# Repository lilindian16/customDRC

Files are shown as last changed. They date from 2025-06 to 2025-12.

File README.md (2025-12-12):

# Custom DRC for the Bit10 DSP

## Reverse Engineering

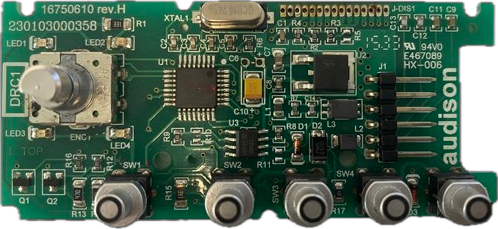
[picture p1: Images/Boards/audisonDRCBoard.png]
Bit10 DRC PCB with screen removed


### Bit10 DRC Schema

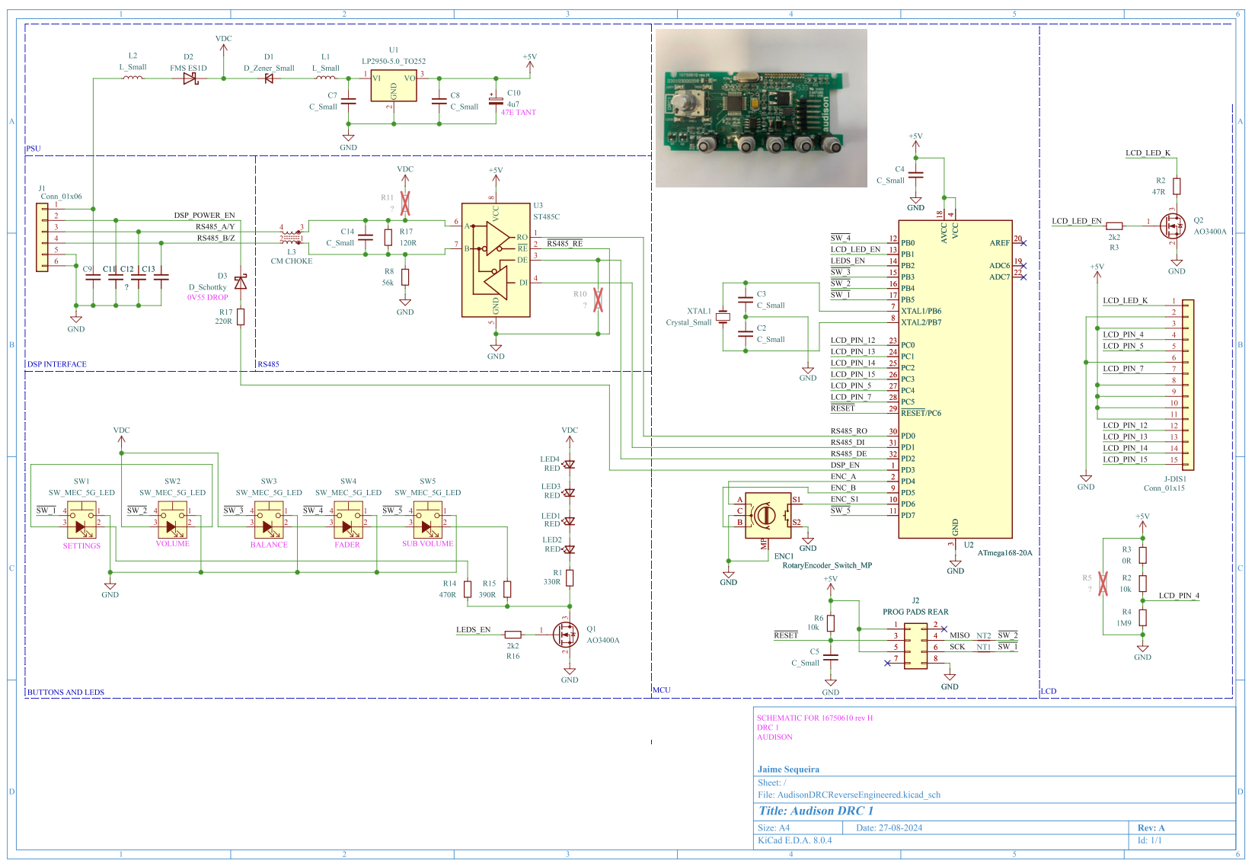
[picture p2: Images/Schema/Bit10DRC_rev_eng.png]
Bit10 DRC schema


## CustomDRC

### Bare PCB

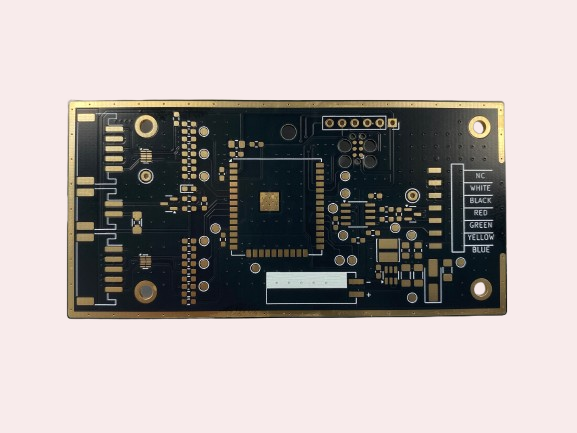
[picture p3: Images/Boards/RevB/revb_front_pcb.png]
Rev B PCB Front


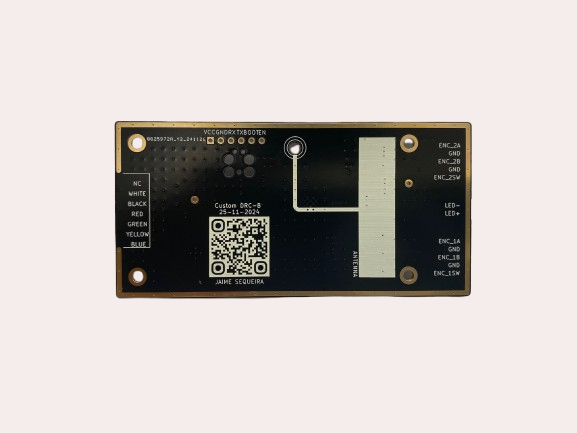
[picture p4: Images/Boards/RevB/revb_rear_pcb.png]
Rev B PCB Rear


### Assembled Board

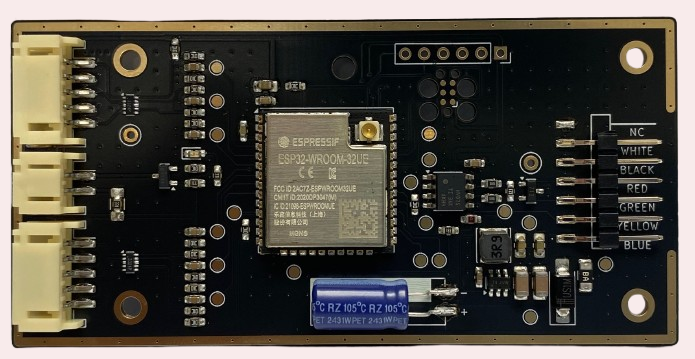
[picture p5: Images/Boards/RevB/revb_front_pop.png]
Reb B PCB Assembled


Boards can be programmed via TC2030 header or 2.54mm pin header (left unpopulated). Once programmed,
further updates can be handled via the OTA Update interface through the local webapp

### Board Bringup - Scope Captures

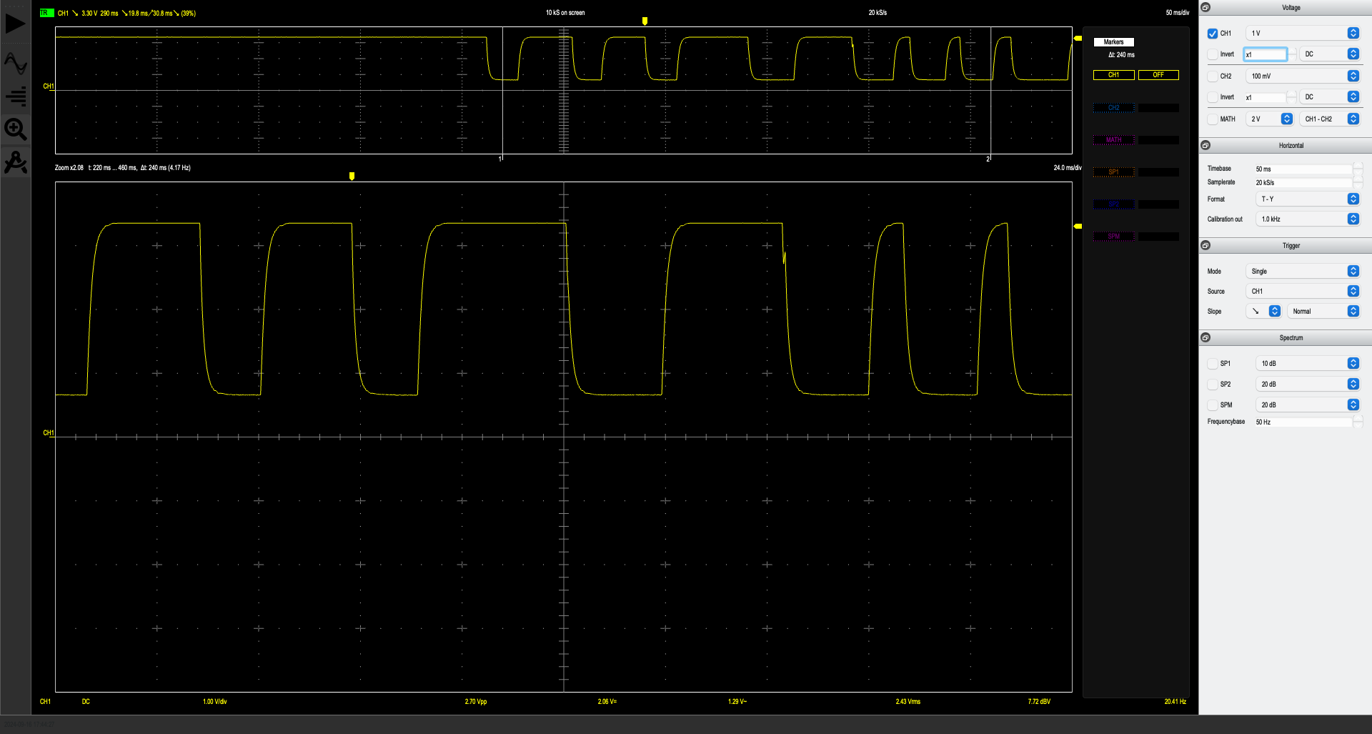
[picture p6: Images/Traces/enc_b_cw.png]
Encoder Pin B during rotation


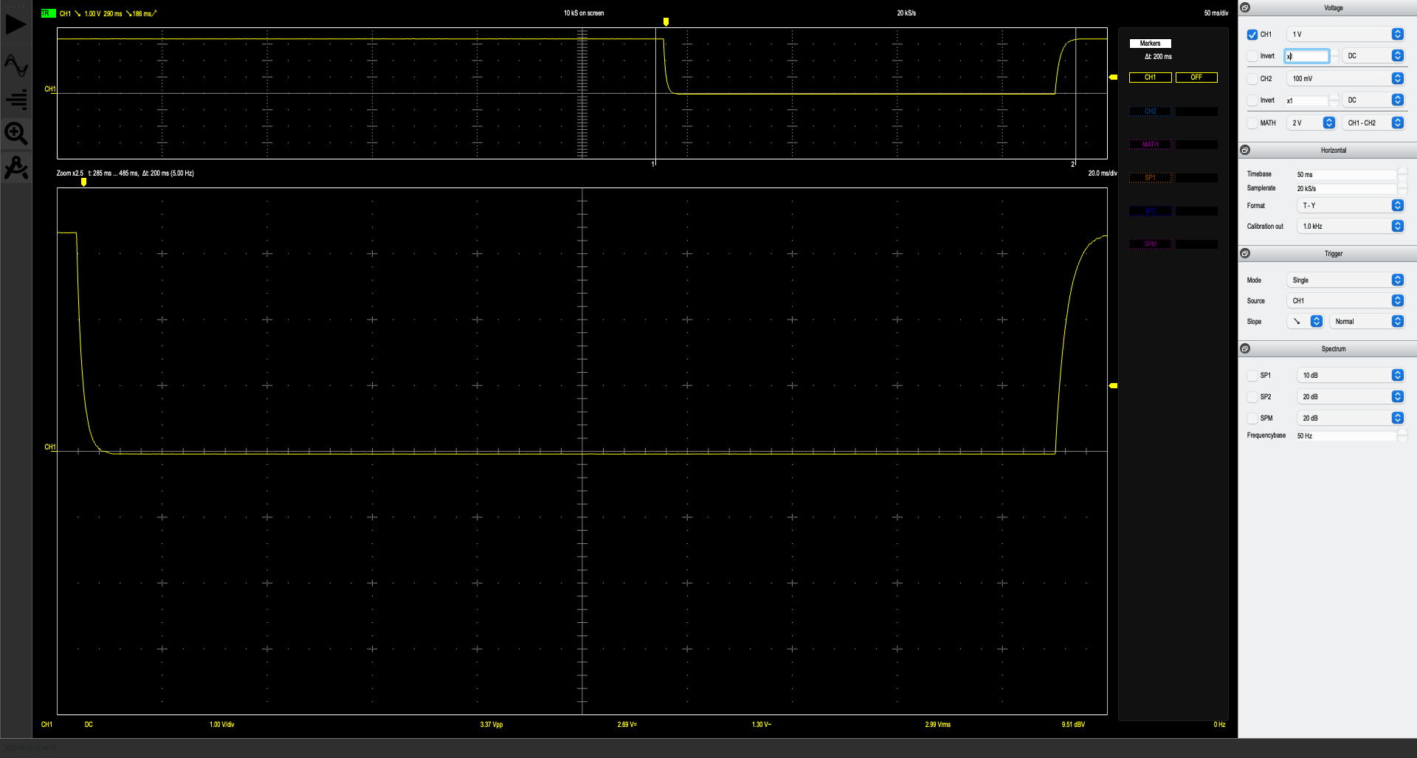
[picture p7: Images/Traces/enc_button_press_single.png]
Capture of button signal on single press


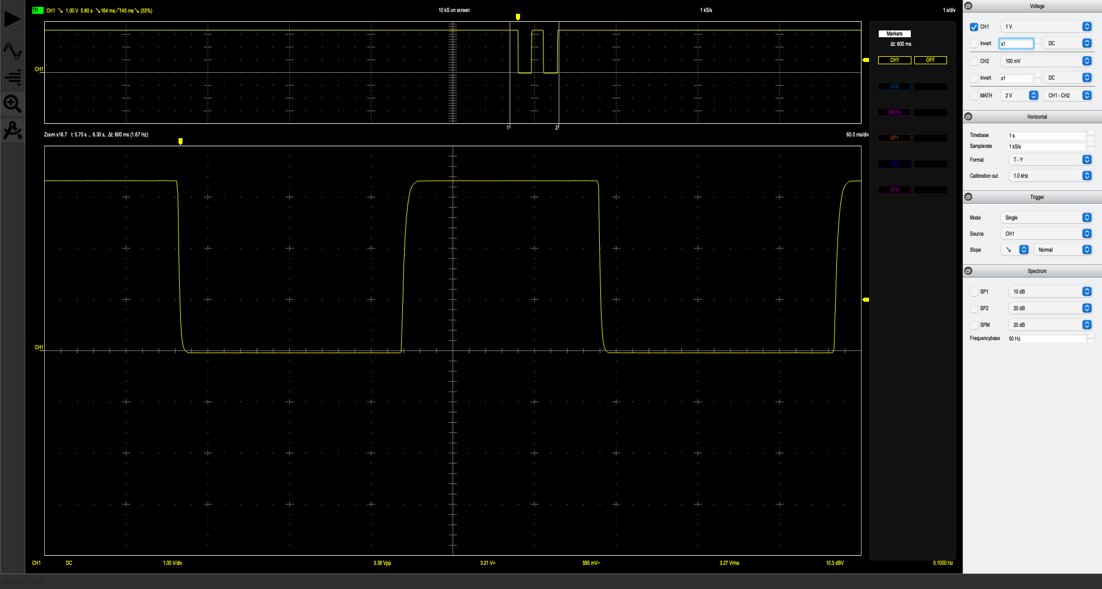
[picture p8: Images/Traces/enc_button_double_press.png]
Capture of button signal with double press


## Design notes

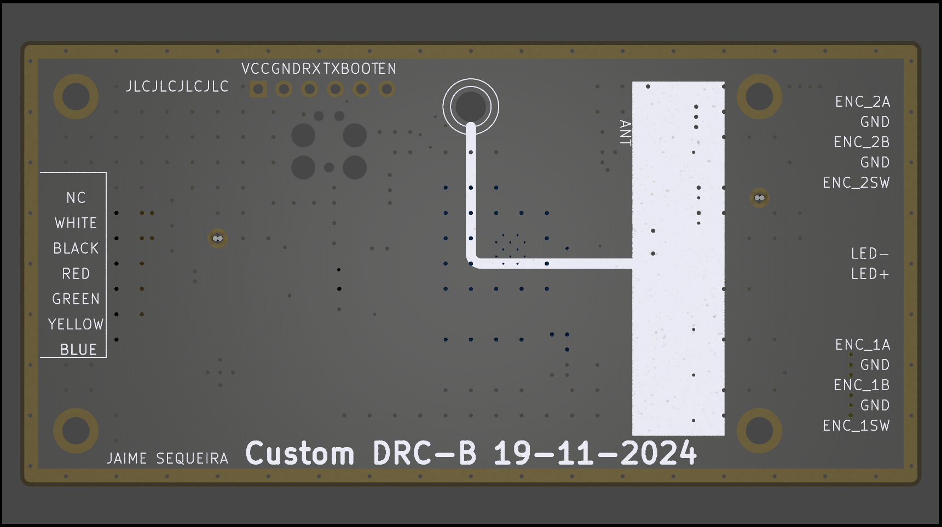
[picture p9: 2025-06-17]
Hardware/CustomDRC/BoardRenders/CDRC_RevB_Bot.png

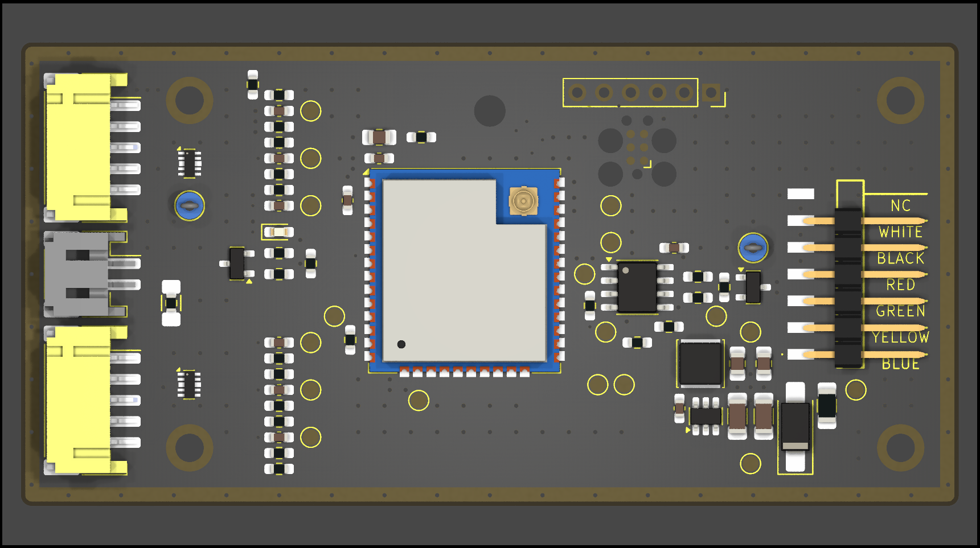
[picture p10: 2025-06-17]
Hardware/CustomDRC/BoardRenders/CDRC_RevB_Top.png

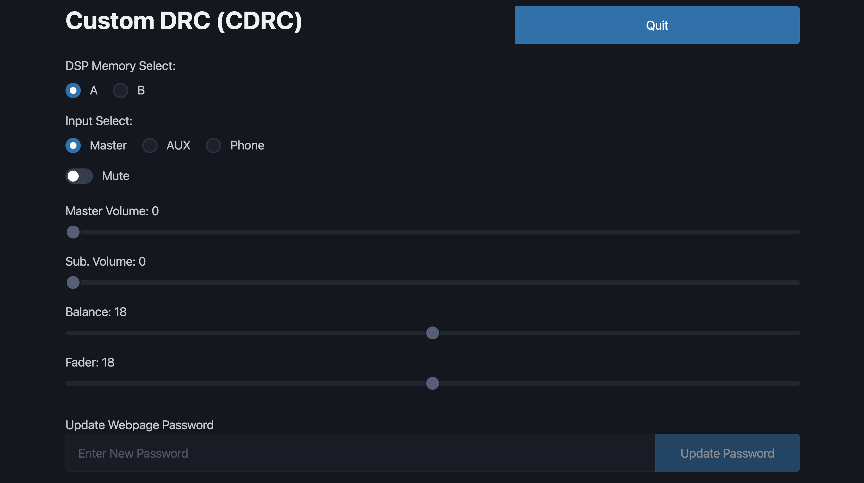
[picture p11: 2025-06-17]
Images/Software/CDRC_mainpage.png

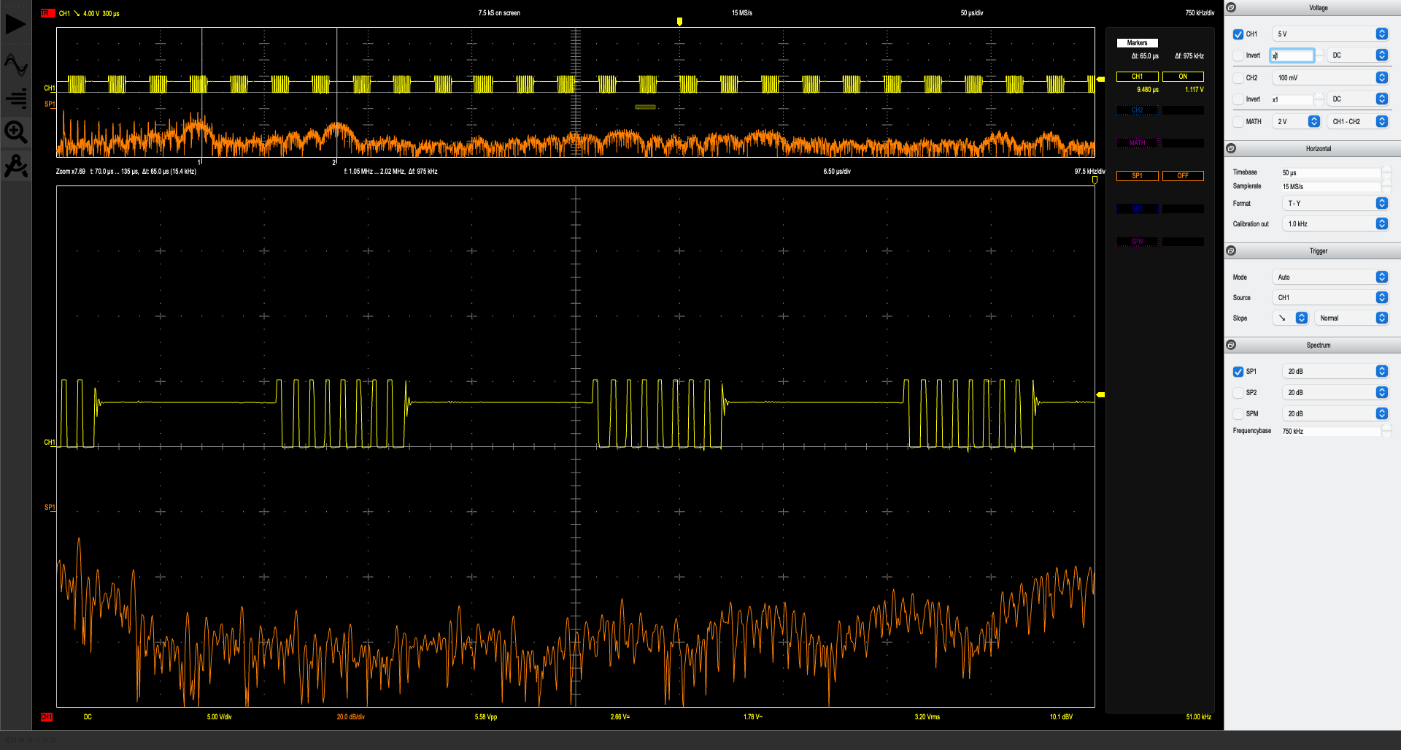
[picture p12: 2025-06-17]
Images/SMPSU/sw_pin_sp1_dp100.png

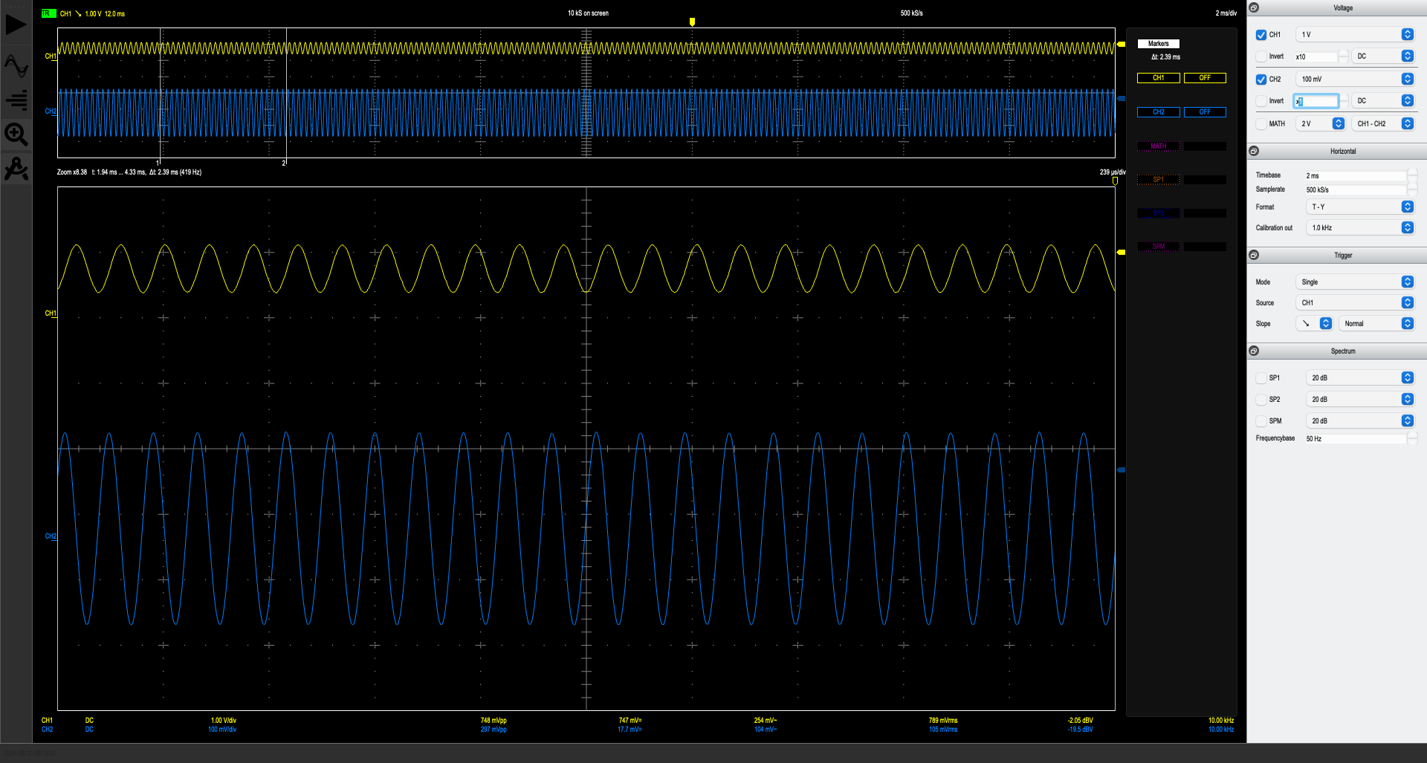
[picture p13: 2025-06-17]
Images/Traces/volume_adjust_0x78_20240821_080611.png

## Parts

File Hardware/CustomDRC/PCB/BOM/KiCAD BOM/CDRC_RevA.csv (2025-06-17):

Reference | Value | Datasheet | Footprint | Qty | DNP | LCSC | MPN | Manufacturer
C201,C301,C501,C502,C503,C504,C505,C506 | 0u1 | ~ | Capacitor_SMD:C_0603_1608Metric_Pad1.08x0.95mm_HandSolder | 8 |  | C14663 | CC0603KRX7R9BB104 | YAGEO
C202,C203 | 10u | ~ | Capacitor_SMD:C_1206_3216Metric_Pad1.33x1.80mm_HandSolder | 2 |  | C89632 | CL31B106KBHNNNE | Samsung Electro-Mechanics
C204,C205,C402 | 22u | ~ | Capacitor_SMD:C_0805_2012Metric_Pad1.18x1.45mm_HandSolder | 3 |  | C45783 | CL21A226MAQNNNE | Samsung Electro-Mechanics
C206,C207 | 2u2 | ~ | Capacitor_SMD:C_0805_2012Metric_Pad1.18x1.45mm_HandSolder | 2 |  | C23630 | CL10A225KO8NNNC | Samsung Electro-Mechanics
C401,C403 | 1u | ~ | Capacitor_SMD:C_0603_1608Metric_Pad1.08x0.95mm_HandSolder | 2 |  | C15849 | CL10A105KB8NNNC | Samsung Electro-Mechanics
D201 | 1N4148WS | ~ | Diode_SMD:D_SOD-323_HandSoldering | 1 |  | C2128 | 1N4148WS | Jiangsu Changjing Electronics Technology Co., Ltd.
D202 | US1M | ~ | Diode_SMD:D_SMA_Handsoldering | 1 |  | C412437 | US1M | MDD(Microdiode Semiconductor)
D301 | SM712 | https://www.littelfuse.com/~/media/electronics/datasheets/tvs_diode_arrays/littelfuse_tvs_diode_array_sm712_datasheet.pdf.pdf | Package_TO_SOT_SMD:SOT-23 | 1 |  | C5243888 | SM712 | JUXING
D401 | LED_Small | ~ | LED_SMD:LED_0603_1608Metric_Pad1.05x0.95mm_HandSolder | 1 |  | C2290 | KT-0603W | Hubei KENTO Elec
F201 | 2A TRIP | ~ | Fuse:Fuse_1206_3216Metric_Pad1.42x1.75mm_HandSolder | 1 |  | C2977524 | BSMD1206-025-33V | BHFUSE
F202 | 1A TRIP | ~ | Fuse:Fuse_0603_1608Metric_Pad1.05x0.95mm_HandSolder | 1 |  | C2844464 | BSMD0603-050-12V | BHFUSE
IC301 | SN65HVD75DR | http://www.ti.com/lit/gpn/sn65hvd75 | Package_SO:SOIC-8_3.9x4.9mm_P1.27mm | 1 |  | C57928 | SN65HVD75DR | Texas Instruments
J101 | DSP Header | ~ | Connector_PinHeader_2.54mm:PinHeader_1x07_P2.54mm_Horizontal | 1 |  | C18905866 | XDZ254-1-06-W-2.5-G1 | chxunda
J501,J504 | JST-PH-2.0-05 | ~ | Connector_JST:JST_PH_B5B-PH-K_1x05_P2.00mm_Vertical | 2 |  | C157993 | B5B-PH-K-S(LF)(SN) | JST
J502 | JST-PH-2.0-02 | ~ | Connector_JST:JST_PH_B2B-PH-K_1x02_P2.00mm_Vertical | 1 |  | C131337 | B2B-PH-K-S(LF)(SN) | JST
L201 | 4u7 | ~ | Inductor_SMD:L_Chilisin_BMRA00040420 | 1 |  | C5307591 | XR0420-4R7M | XR
Q501 | AO3400A | http://www.aosmd.com/pdfs/datasheet/AO3400A.pdf | Package_TO_SOT_SMD:SOT-23 | 1 |  | C20917 | AO3400A | Alpha & Omega Semicon
R201 | 0R | ~ | Resistor_SMD:R_0603_1608Metric_Pad0.98x0.95mm_HandSolder | 1 |  | C21189 | 0603WAF0000T5E | UNI-ROYAL(Uniroyal Elec)
R301,R305,R401,R502,R504,R505,R506,R507,R508,R509,R510,R511,R512,R513,R514,R515 | 10k | ~ | Resistor_SMD:R_0603_1608Metric_Pad0.98x0.95mm_HandSolder | 16 |  | C25804 | 0603WAF1002T5E | UNI-ROYAL(Uniroyal Elec)
R302,R304 | 10R | ~ | Resistor_SMD:R_0603_1608Metric_Pad0.98x0.95mm_HandSolder | 2 |  | C2091419 | CRCW060310R0FKTA | Vishay Intertech
R303 | 120R | ~ | Resistor_SMD:R_0603_1608Metric_Pad0.98x0.95mm_HandSolder | 1 |  | C22787 | 0603WAF1200T5E | UNI-ROYAL(Uniroyal Elec)
R402,R403,R501,R503 | 330R | ~ | Resistor_SMD:R_0603_1608Metric_Pad0.98x0.95mm_HandSolder | 4 |  | C23138 | 0603WAF3300T5E | UNI-ROYAL(Uniroyal Elec)
TP101,TP508 | TestPoint_Small | ~ | TestPoint:TestPoint_Keystone_5000-5004_Miniature | 2 |  | C5199801 | RH-5001 | ronghe
U201 | AP63205WU-7 | https://www.diodes.com/assets/Datasheets/AP63200-AP63201-AP63203-AP63205.pdf | Package_TO_SOT_SMD:TSOT-23-6 | 1 |  | C2071056 | AP63205WU-7 | Diodes Incorporated
U202 | TLV76733DRVR | www.ti.com/lit/gpn/TLV767 | Package_SON:WSON-6-1EP_2x2mm_P0.65mm_EP1x1.6mm_ThermalVias | 1 |  | C2848334 | TLV76733DRVR | Texas Instruments
U401 | ESP32-WROOM-32UE-R2 | https://www.espressif.com/sites/default/files/documentation/esp32-wroom-32e_esp32-wroom-32ue_datasheet_en.pdf | RF_Module:ESP32-WROOM-32UE | 1 |  | C701346 | ESP32-WROOM-32UE-N16 | Espressif Systems
U501,U502 | ESD224DQA | https://www.ti.com/lit/ds/symlink/esd224.pdf | Package_DFN_QFN:Diodes_UDFN-10_1.0x2.5mm_P0.5mm | 2 |  | C5199157 | RClAMP3324P-ES | ElecSuper

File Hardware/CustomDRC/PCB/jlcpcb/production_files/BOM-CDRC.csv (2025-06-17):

Comment | Designator | Footprint | LCSC | Quantity
0u1 | C201,C301,C501,C502,C503,C504,C505,C506 | C_0603_1608Metric_Pad1.08x0.95mm_HandSolder | C14663 | 8
1u | C401,C403 | C_0603_1608Metric_Pad1.08x0.95mm_HandSolder | C15849 | 2
100U |  | Capacitor_D6.3xL12mm_SMD | C160200 | 0
DSP Header | J101 | M208900705 | C20610239 | 1
10R | R302,R304 | R_0603_1608Metric_Pad0.98x0.95mm_HandSolder | C2091419 | 2
AO3400A | Q501 | SOT-23 | C20917 | 1
0R | R201 | R_0603_1608Metric_Pad0.98x0.95mm_HandSolder | C21189 | 1
120R | R303 | R_0603_1608Metric_Pad0.98x0.95mm_HandSolder | C22787 | 1
WHITE OR BLUE | D401 | LED_0603_1608Metric_Pad1.05x0.95mm_HandSolder | C2290 | 1
330R | R402,R403,R501,R503 | R_0603_1608Metric_Pad0.98x0.95mm_HandSolder | C23138 | 4
10k | R301,R305,R401,R502,R504,R505,R506,R507,R508,R509,R510,R511,R512,R513,R514,R515 | R_0603_1608Metric_Pad0.98x0.95mm_HandSolder | C25804 | 16
JST_PH_S5B-PH-SM4 | J501,J504 | JST_PH_S5B-PH-SM4-TB_1x05-1MP_P2.00mm_Horizontal | C265104 | 2
JST_PH_S2B-PH-SM4 | J502 | JST_PH_S2B-PH-SM4-TB_1x02-1MP_P2.00mm_Horizontal | C295747 | 1
BSMD1206-025-33V | F201 | Fuse_1206_3216Metric_Pad1.42x1.75mm_HandSolder | C2977524 | 1
US1M | D202 | D_SMA_Handsoldering | C412437 | 1
22u | C204,C205,C402 | C_0805_2012Metric_Pad1.18x1.45mm_HandSolder | C45783 | 3
ESD224DQA | U501,U502 | Diodes_UDFN-10_1.0x2.5mm_P0.5mm | C5199157 | 2
SM712 | D301 | SOT-23 | C5243888 | 1
SN65HVD75DR | IC301 | SOIC-8_3.9x4.9mm_P1.27mm | C57928 | 1
ESP32-WROOM-32UE-R2 | U401 | ESP32-WROOM-32UE | C701346 | 1
AP63203WU-7 | U201 | TSOT-23-6 | C780769 | 1
10u | C202,C203 | C_1206_3216Metric_Pad1.33x1.80mm_HandSolder | C89632 | 2
3u9 | L201 | L_Cenker_CKCS4030 | C96899 | 1

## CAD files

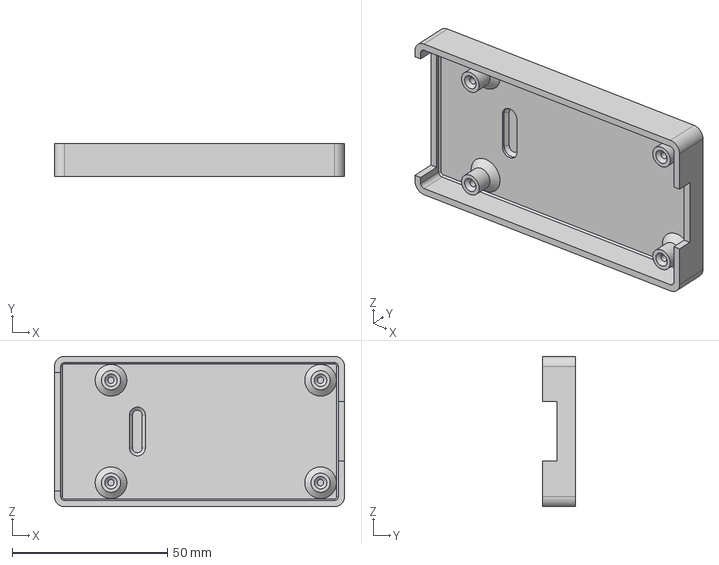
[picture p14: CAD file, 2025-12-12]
Hardware/CustomDRC/Housing/CustomDRC_Cover.step
93.4 x 10.6 x 48.4 mm

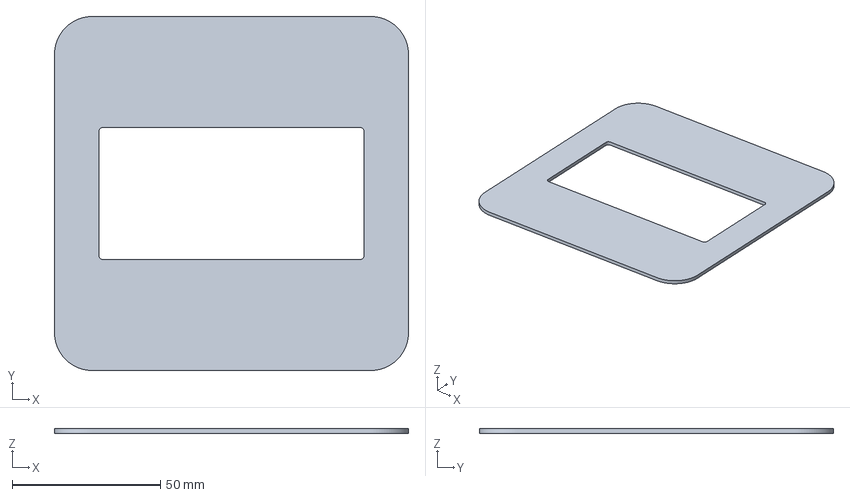
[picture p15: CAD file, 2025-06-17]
Hardware/CustomDRC/PCB/Stencil_Jig/CDRC_RevB_Stencil_Jig.3mf
119.5 x 119.5 x 1.60 mm

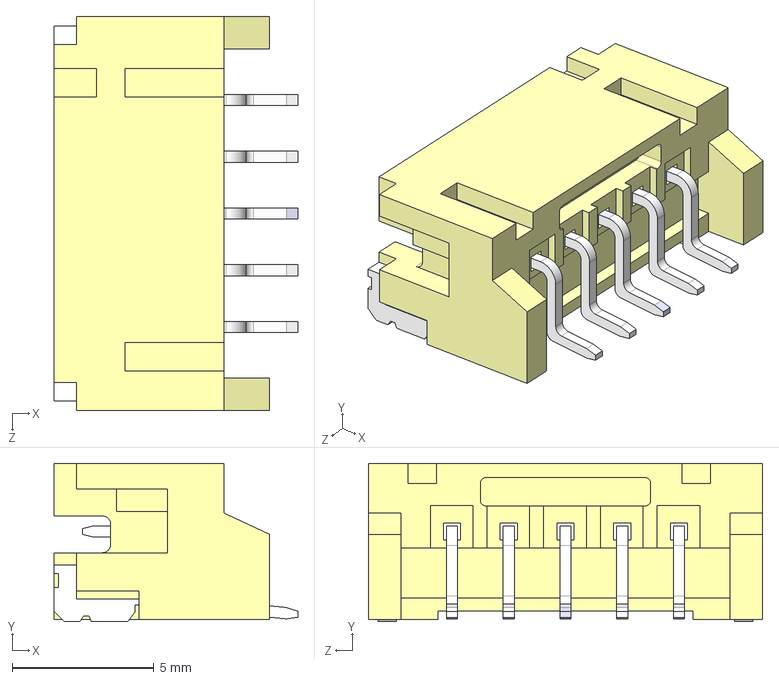
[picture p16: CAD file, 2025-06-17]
Hardware/CustomDRC/PCB/KiCadLibs/Models/S5B-PH-SM4-TB_LF__SN_.stp
8.60 x 5.58 x 13.9 mm

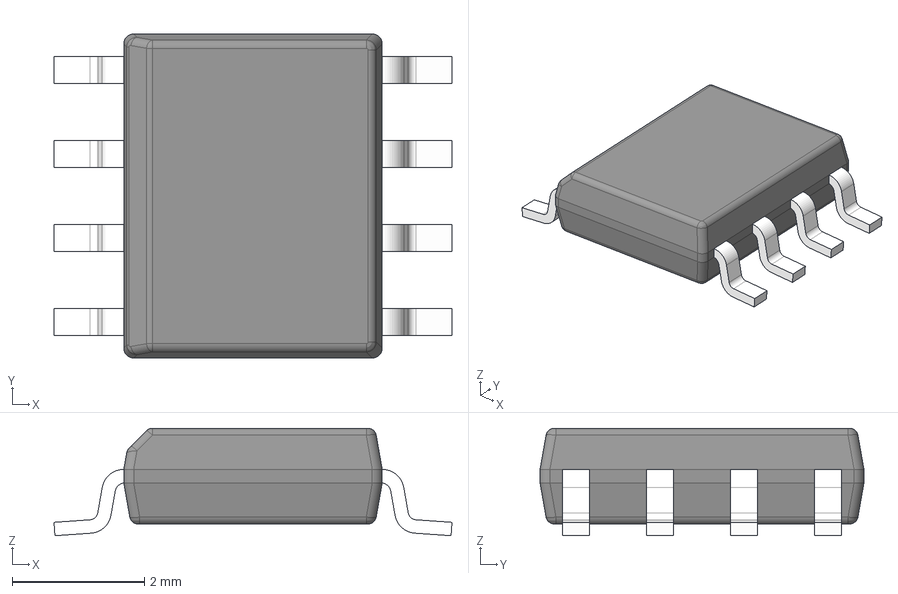
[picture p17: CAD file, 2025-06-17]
Hardware/CustomDRC/PCB/KiCadLibs/Models/SN65HVD75DR.stp
6.02 x 4.90 x 1.63 mm
BODY-SO
LEAD-D0008A x 8

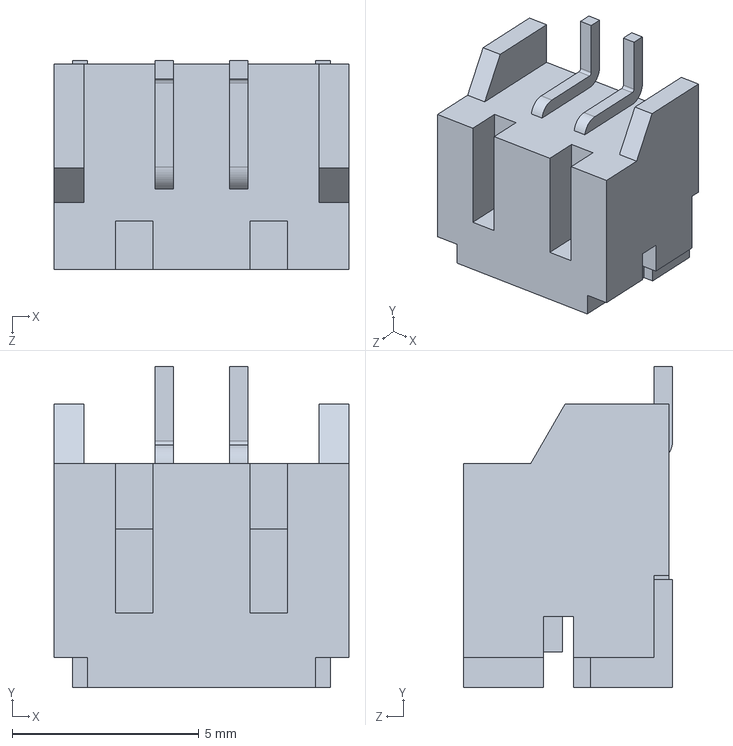
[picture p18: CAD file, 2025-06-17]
Hardware/CustomDRC/PCB/KiCadLibs/Models/S2B-PH-SM4-TB_LF__SN_.stp
7.90 x 8.60 x 5.60 mm

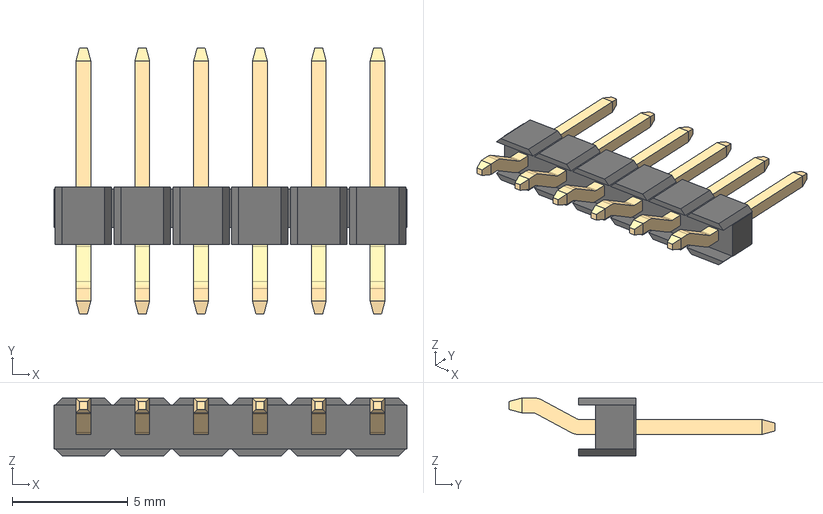
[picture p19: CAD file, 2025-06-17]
Hardware/CustomDRC/PCB/KiCadLibs/Models/M20-8890645.stp
15.2 x 11.5 x 2.50 mm
M20-88906_MOULD
M20-889_CONTACT x 6

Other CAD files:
Hardware/CustomDRC/BoardModels/CDRC-B_Silkscreen.dxf
Hardware/CustomDRC/BoardModels/CDRC-F_Silkscreen.dxf
Hardware/CustomDRC/Housing/CustomDRC_Cover.stl
Hardware/CustomDRC/PCB/PCB_Model/SS_Layer_DXF/CDRC-B_Silkscreen.dxf
Hardware/CustomDRC/PCB/PCB_Model/SS_Layer_DXF/CDRC-F_Silkscreen.dxf
Hardware/CustomDRC/PCB/Stencil_Jig/CDRC_RevB_Stencil_Jig.stl

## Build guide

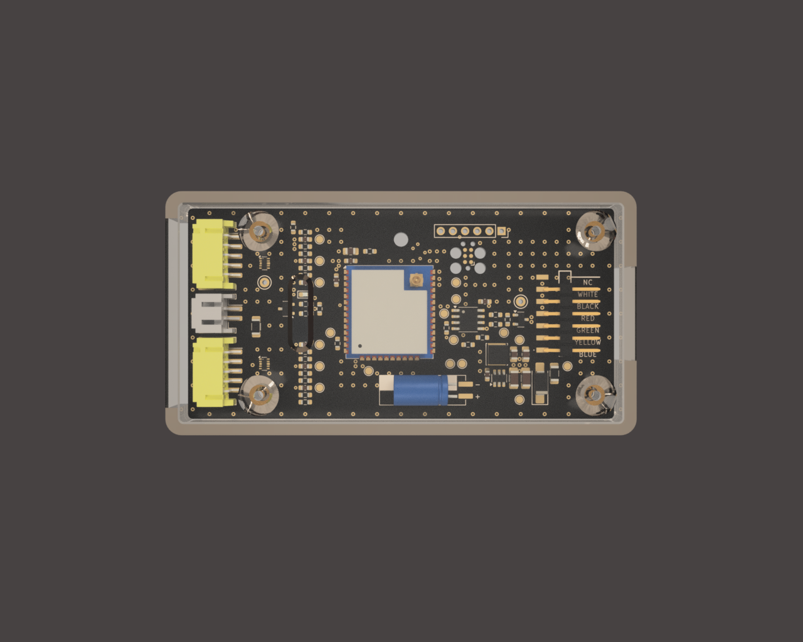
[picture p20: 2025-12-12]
Hardware/CustomDRC/BoardRenders/CDRC_RevB_Assembly_2025-Dec-10_07-59-26PM-000_CustomizedView10631049547.png

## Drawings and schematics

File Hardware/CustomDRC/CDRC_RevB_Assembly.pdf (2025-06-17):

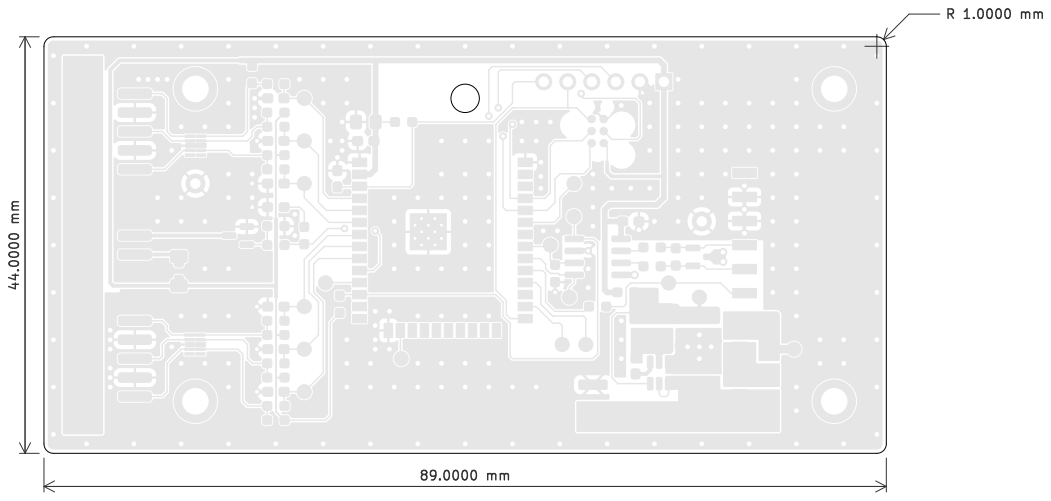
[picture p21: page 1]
D Date: 25-11-2024 KiCad; E.D.A. 8.0.4 Size: A4; Rev:; File: CDRC.kicad_pcb Sheet: BoardDimensions JS; Board2Pdf:; BoardDimensions; Page

Id: 1/1 Title: Custom DRC

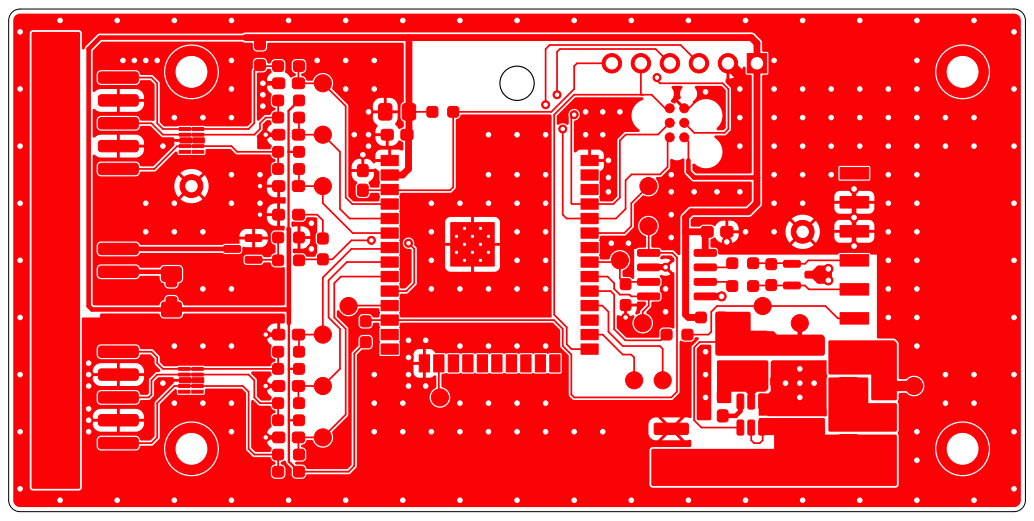
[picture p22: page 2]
D Date: 25-11-2024 KiCad; E.D.A. 8.0.4 Size: A4; Rev:; Board2Pdf:; FrontCU -; Page 2/11

File: CDRC.kicad_pcb Sheet: FrontCU
Id: 1/1 Title: Custom DRC

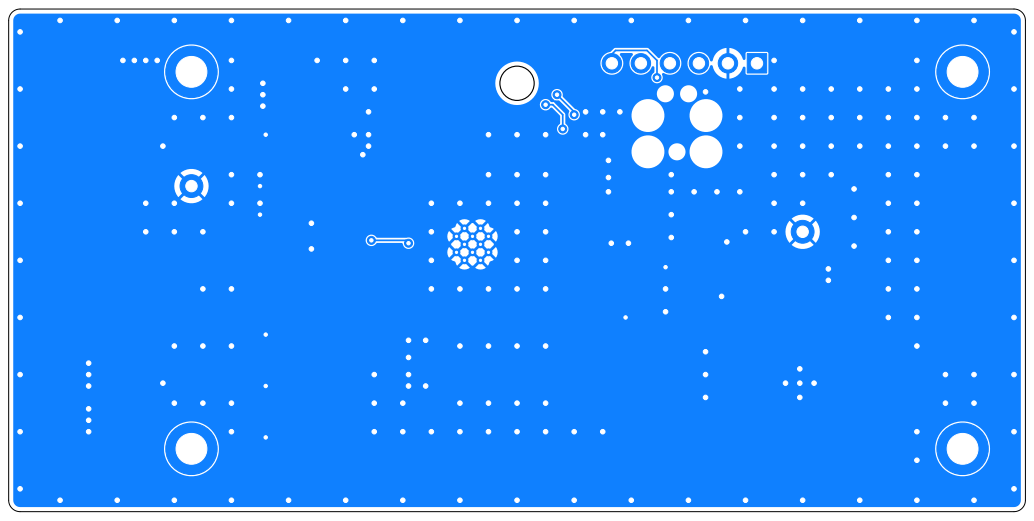
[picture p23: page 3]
D Date: 25-11-2024 KiCad; E.D.A. 8.0.4 Size: A4; Rev:; Board2Pdf:; BackCU -; Page 3/11

File: CDRC.kicad_pcb Sheet: BackCU
Id: 1/1 Title: Custom DRC

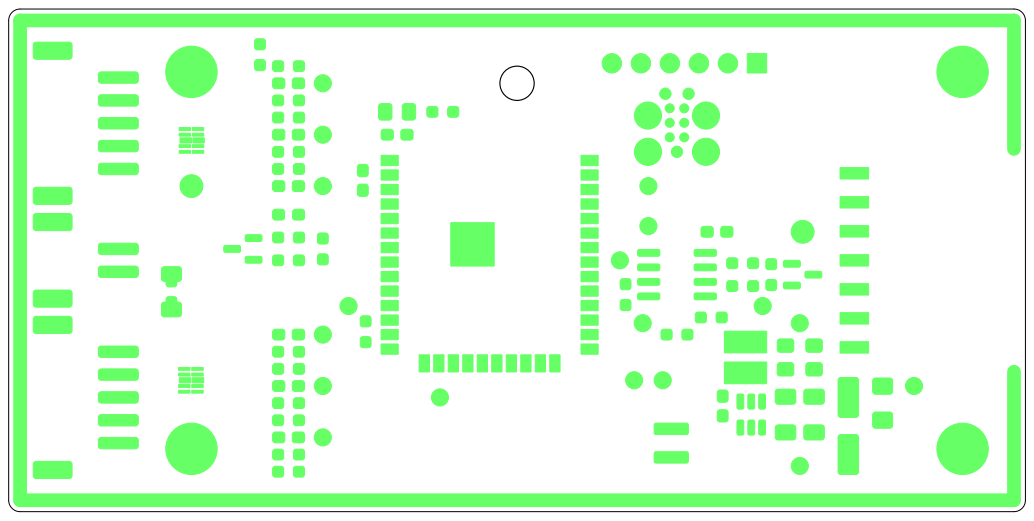
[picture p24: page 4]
D Date: 25-11-2024 KiCad; E.D.A. 8.0.4 Size: A4; Rev:; File: CDRC.kicad_pcb Sheet: FrontMask JS; Board2Pdf:; FrontMask; Page 4/11

Id: 1/1 Title: Custom DRC

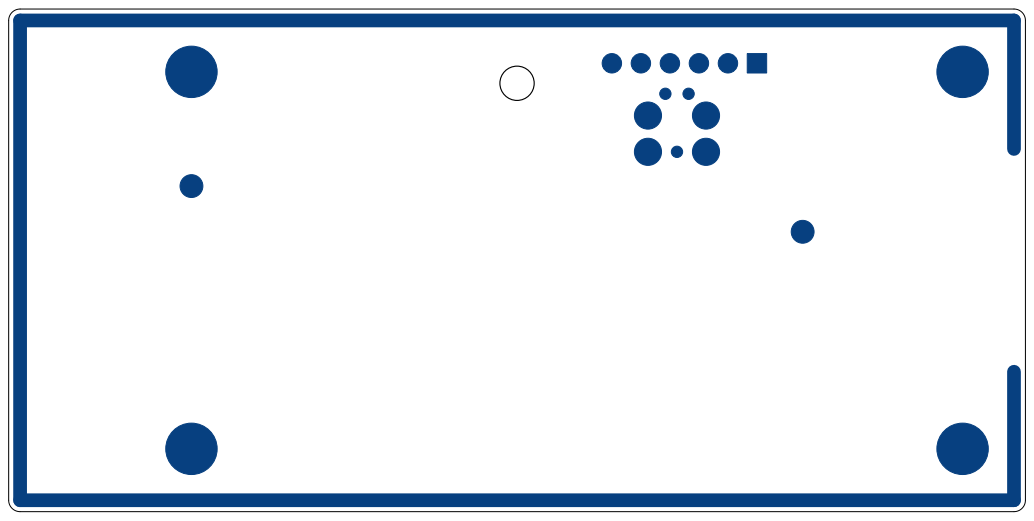
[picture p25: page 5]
D Date: 25-11-2024 KiCad; E.D.A. 8.0.4 Size: A4; Rev:; File: CDRC.kicad_pcb Sheet: BackMask JS; Board2Pdf:; BackMask; Page 5/11

Id: 1/1 Title: Custom DRC

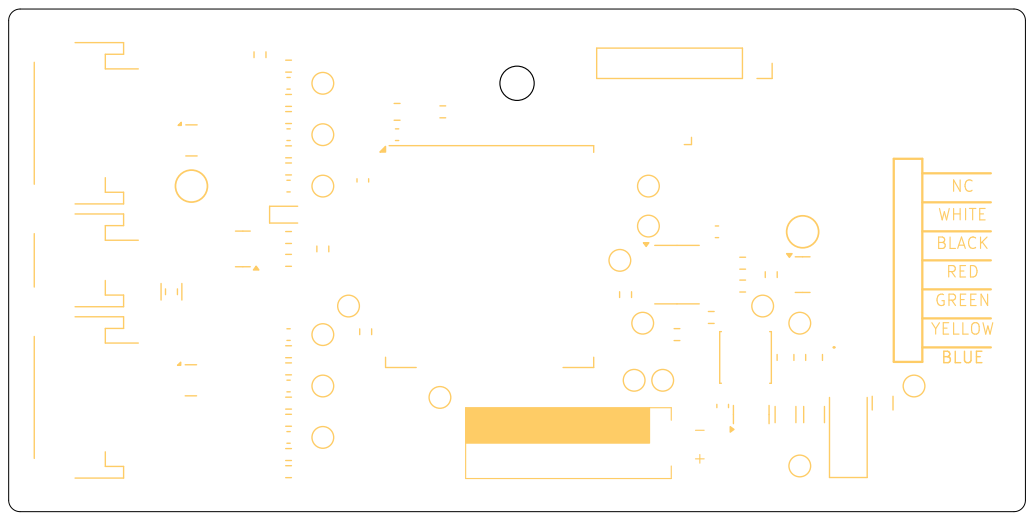
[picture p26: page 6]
YELLOW; D Date: 25-11-2024 KiCad; E.D.A. 8.0.4 Size: A4; Rev:; Board2Pdf:; FrontSS -; Page 6/11

BLUE WHITE GREEN
BLACK
RED

File: CDRC.kicad_pcb Sheet: FrontSS
Id: 1/1 Title: Custom DRC

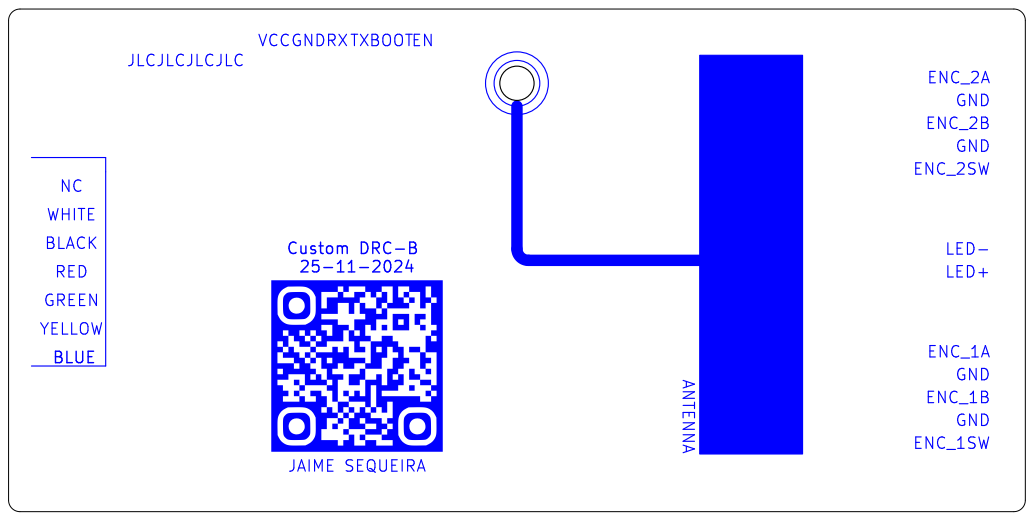
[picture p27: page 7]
GND; JLCJLCJLCJLC GREEN; ENC_2SW; RED; LED- VCC; ENC_1B Custom DRC-B; JAIME SEQUEIRA NC; GND ANTENNA; BLUE WHITE; YELLOW; BLACK; ENC_1SW; ENC_2A; ENC_1A GND 1; D Date: 25-11-2024 KiCad; E.D.A. 8.0.4 Size: A4; Rev:; Board2Pdf:; BackSS -; Page 7/11

LED+ ENC_2B RX BOOT

File: CDRC.kicad_pcb Sheet: BackSS
Id: 1/1 Title: Custom DRC

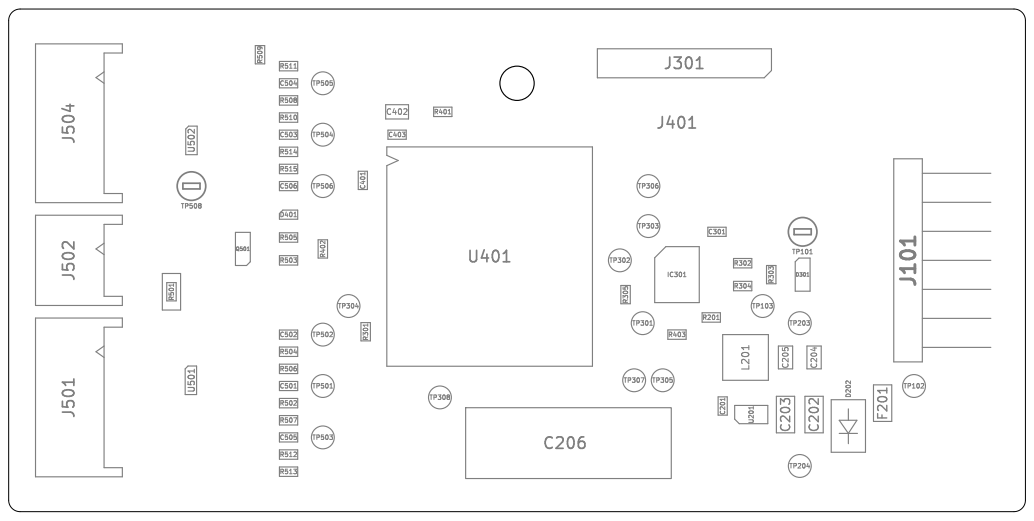
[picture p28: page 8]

File: CDRC.kicad_pcb Sheet: FrontFab
Id: 1/1 Title: Custom DRC

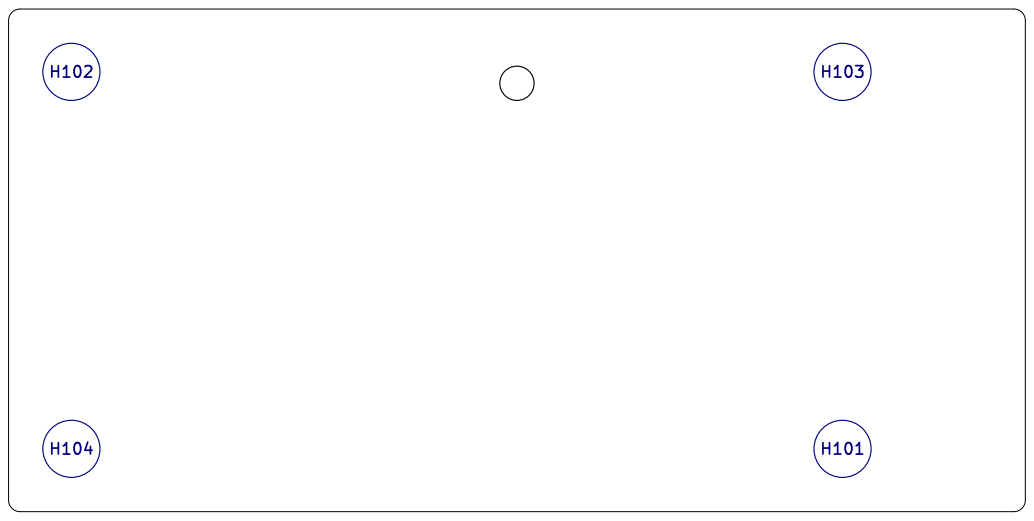
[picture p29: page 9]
D Date: 25-11-2024 KiCad; E.D.A. 8.0.4 Size: A4; Rev:; Board2Pdf:; BackFab; Page 9/11

File: CDRC.kicad_pcb Sheet: BackFab
Id: 1/1 Title: Custom DRC

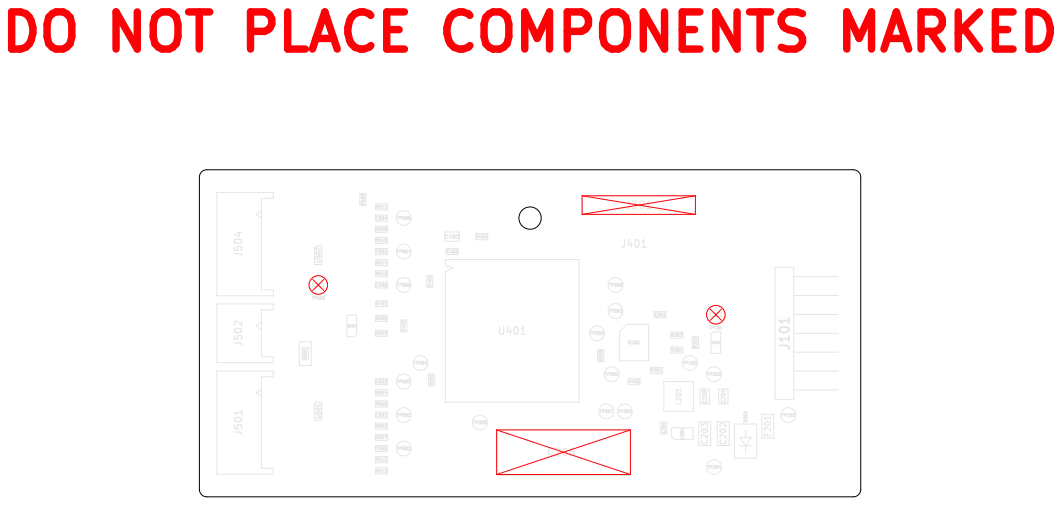
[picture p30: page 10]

File: CDRC.kicad_pcb Sheet: FrontDNP
Id: 1/1 Title: Custom DRC

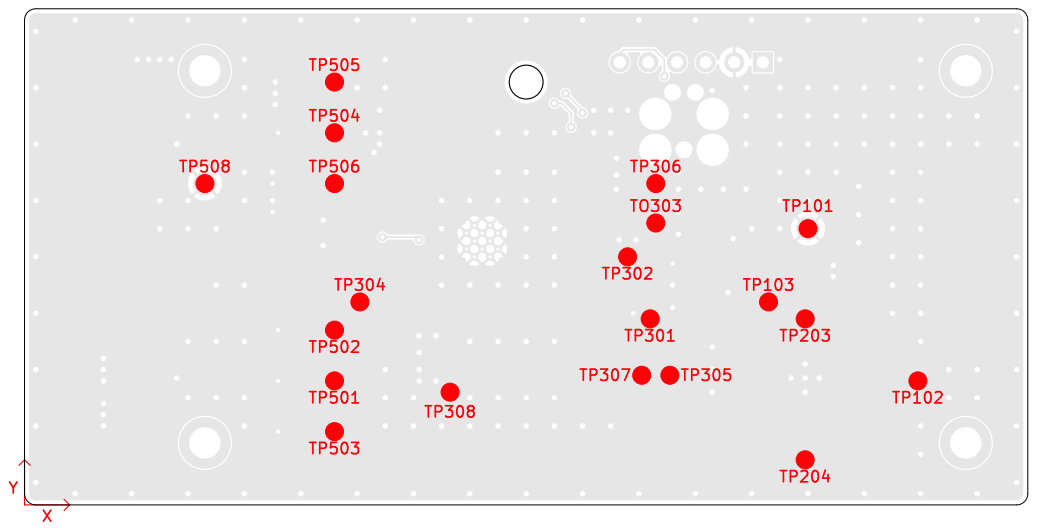
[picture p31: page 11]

File: CDRC.kicad_pcb Sheet: FrontTP
Id: 1/1 Title: Custom DRC

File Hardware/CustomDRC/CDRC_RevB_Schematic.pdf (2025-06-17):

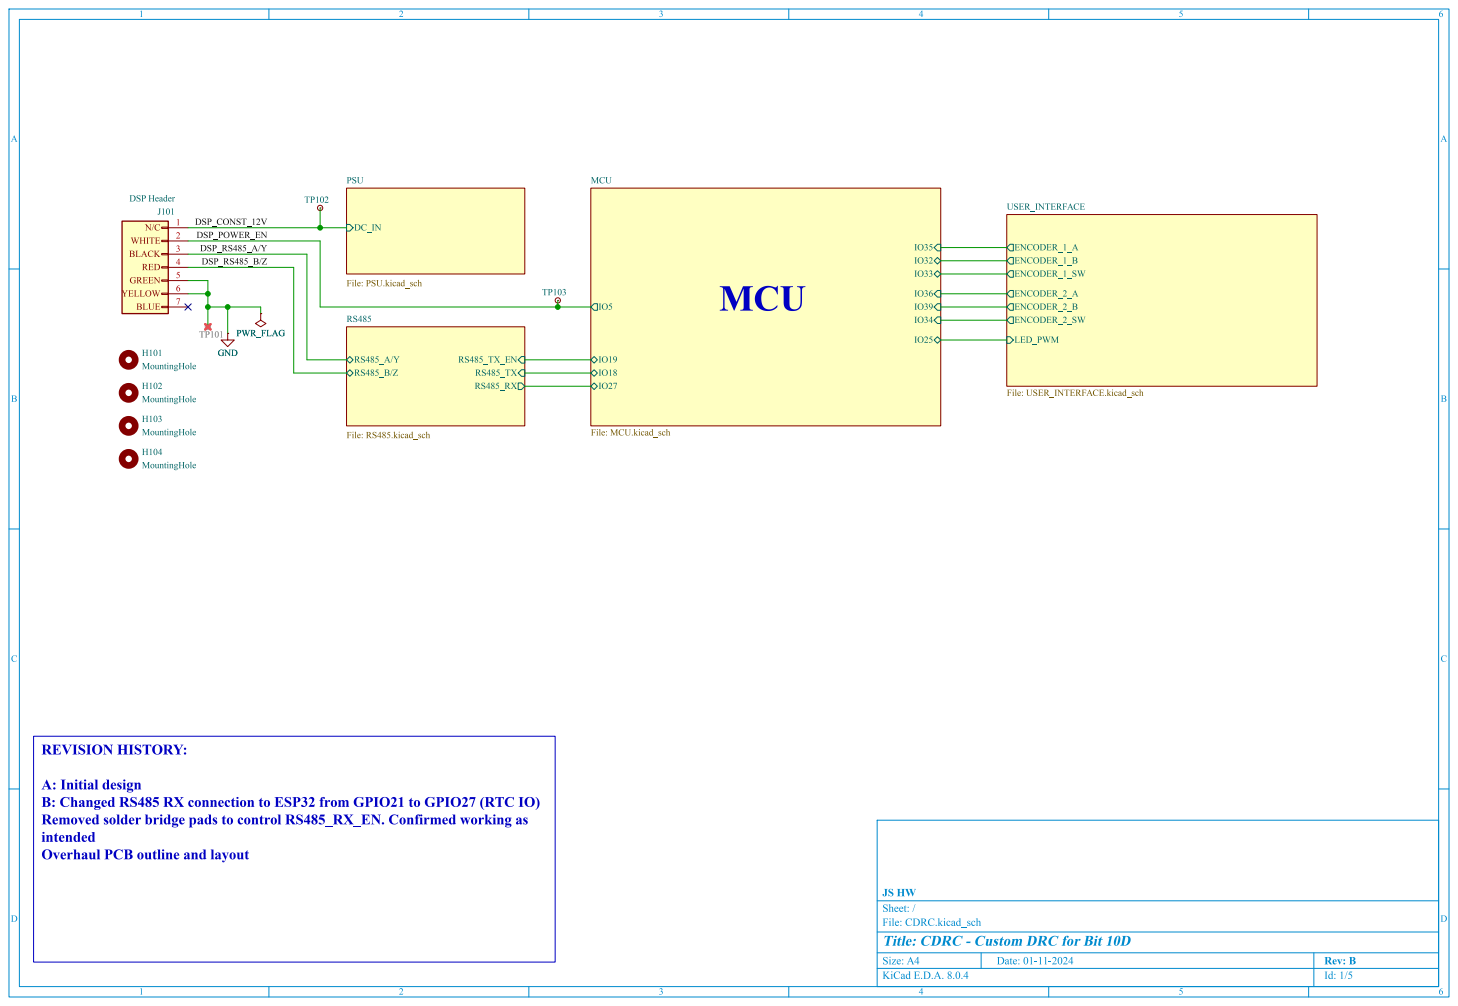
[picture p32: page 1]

File: CDRC.kicad_sch Sheet:/ JSHW

Id: 1/5 Title: CDRC - CustomDRC for Bit 10D


ISAT>= 3A R < 100mRFOREFFICIENCY DC IN IS PROTECTEDUPSTREAMBY MOV AND DAMPING CAPS100VRATED

File: PSU.kicad_sch Sheet:/PSU/ JSHW

Id: 2/5 Title: CDRC - CustomDRC for Bit 10D


1 SWDIO 2 ~{RESET} 3 SWCLK 4 GND

STRAPPINGPINS: GPIO0:BOOTMODE GPIO2:MUST BE FLOATING OR LOW TO ENTERFLASHING MODE GPIO6-GPIO11- INTEGRATEDFLASH SPIPINS GPIO12:FAILS TO BOOTIF PULLED HIGH GPIO14:OUTPUTSPWM ON BOOT GPIO15:OUTPUTSPWM ON BOOT& STRAPPING

File: MCU.kicad_sch Sheet:/MCU/ JSHW

Id: 3/5 Title: CDRC - CustomDRC for Bit 10D


TVS PROTAS PERDATASHEETFIG. 31PG25 AND BOM TABLE. 4 PG22 PULSEPROOF
THICK FILM

Id: 4/5 Title: CDRC - CustomDRC for Bit 10D


ENC_1_A | 1

Id: 5/5 Title: CDRC - CustomDRC for Bit 10D

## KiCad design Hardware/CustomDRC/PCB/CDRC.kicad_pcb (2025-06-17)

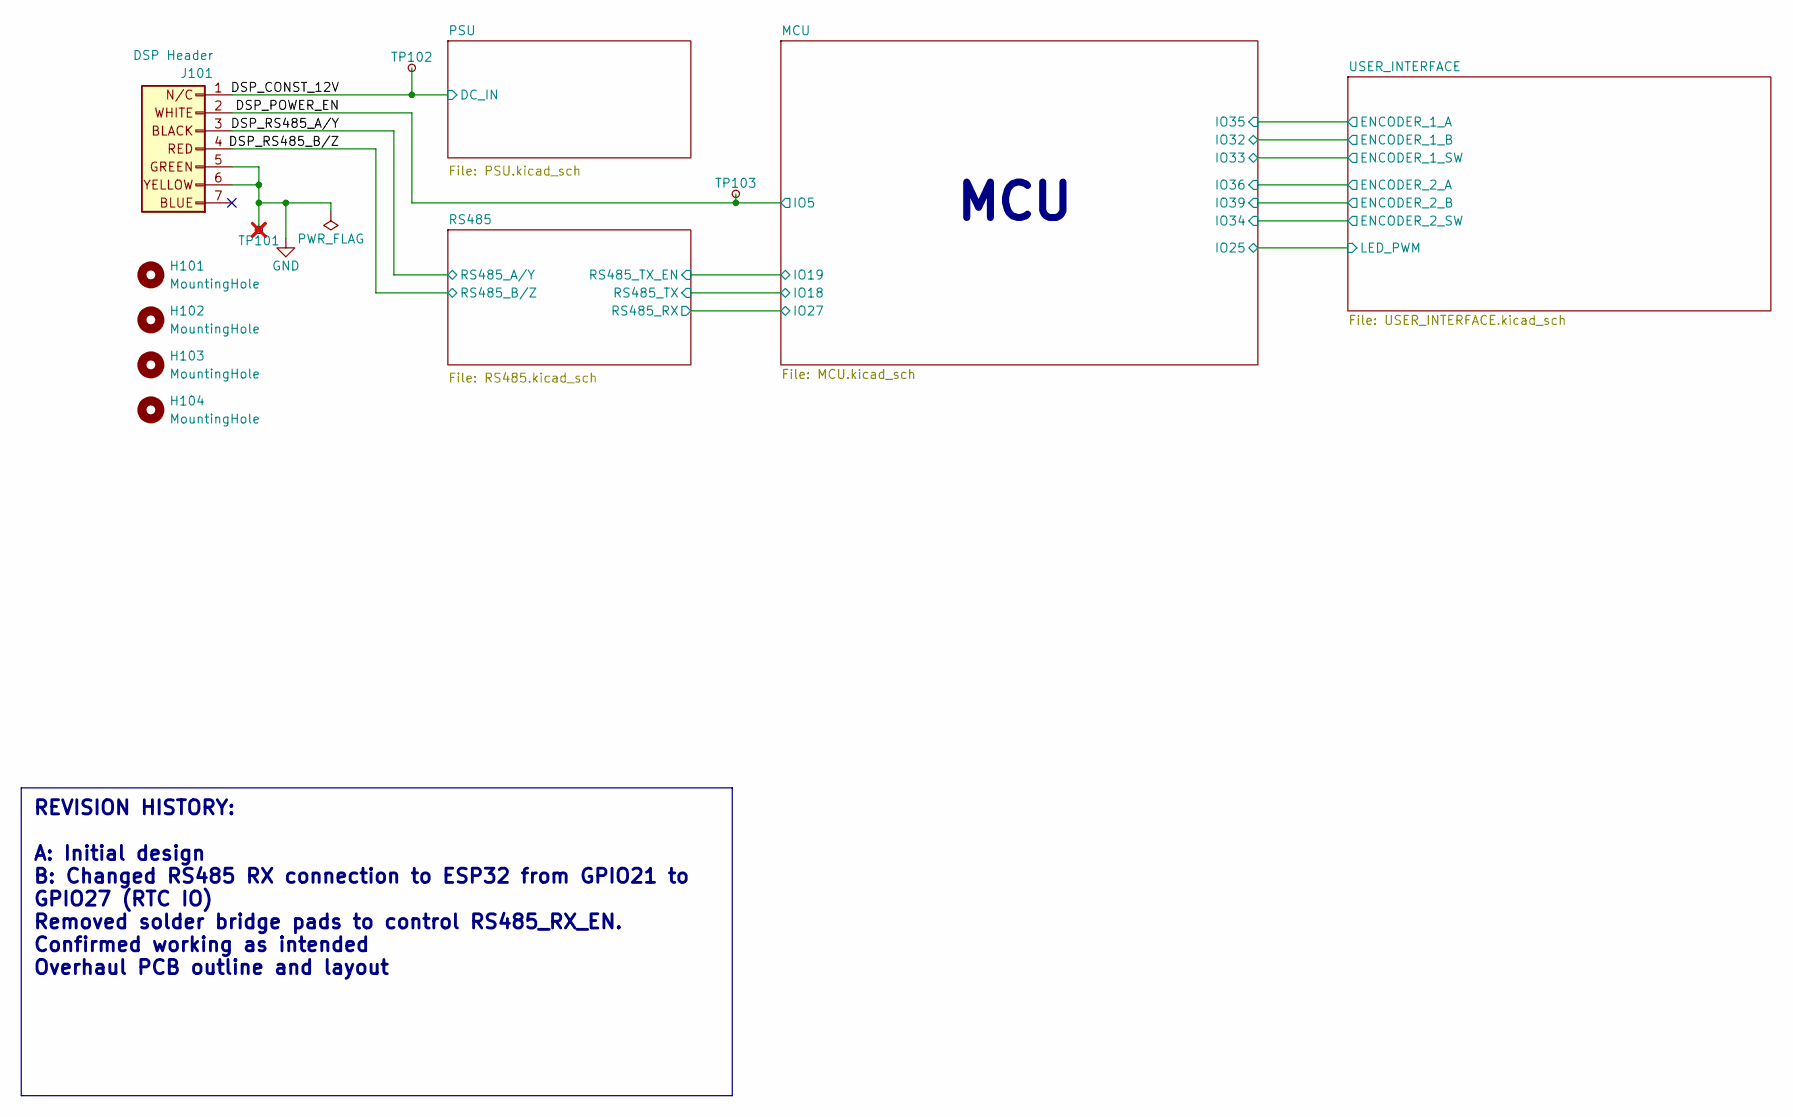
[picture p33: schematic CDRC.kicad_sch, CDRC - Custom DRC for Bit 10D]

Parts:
H101, H102, H103, H104: MountingHole; MountingHole_2.7mm_M2.5_ISO7380_Pad_TopBottom
J101: DSP Header; M208900705; MPN KH-2.54PH-1X30P-L13.5-WT; LCSC C20610239
TP101: TestPoint_Small; TestPoint_Keystone_5000-5004_Miniature; MPN RH-5001; LCSC C5199801; not fitted
TP102, TP103: TestPoint_Small; TestPoint_Pad_D1.5mm

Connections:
/DSP_CONST_12V: J101.1, TP102.1; also elsewhere on the board
/DSP_POWER_EN: J101.2, TP103.1; also elsewhere on the board
/DSP_RS485_A/Y: J101.3; also elsewhere on the board
/DSP_RS485_B/Z: J101.4; also elsewhere on the board
GND: J101.5, J101.6, TP101.1; also elsewhere on the board

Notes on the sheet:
REVISION HISTORY: A: Initial design B: Changed RS485 RX connection to ESP32 from GPIO21 to GPIO27 (RTC IO) Removed solder bridge pads to control RS485_RX_EN. Confirmed working as intended Overhaul PCB outline and layout
MCU

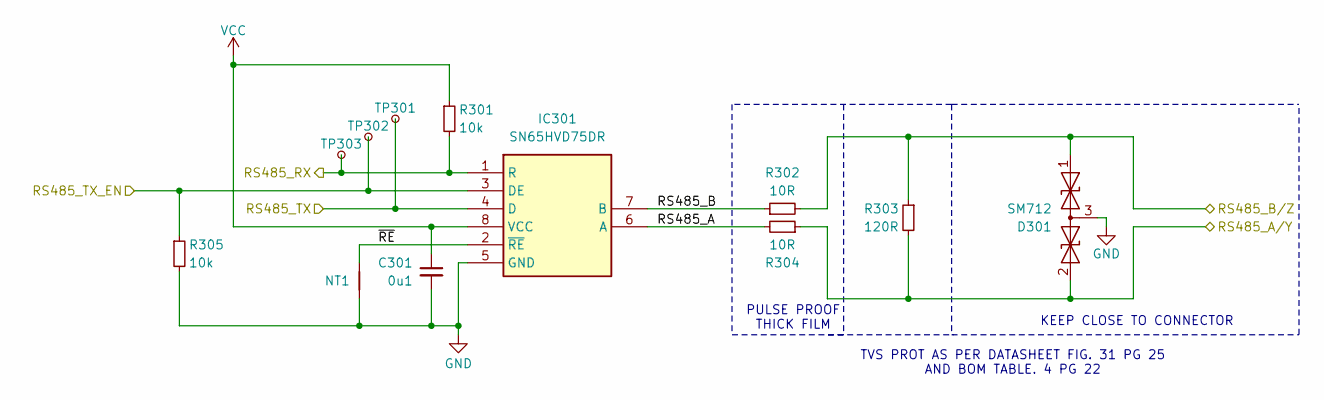
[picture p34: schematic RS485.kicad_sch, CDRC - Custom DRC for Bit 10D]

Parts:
C301: 0u1; C_0603_1608Metric_Pad1.08x0.95mm_HandSolder; MPN CC0603KRX7R9BB104; LCSC C14663
D301: SM712; SOT-23; MPN SM712; LCSC C5243888
IC301: SN65HVD75DR; SOIC-8_3.9x4.9mm_P1.27mm; Manufacturer_Part_Number SN65HVD75DR; Mouser Part Number 595-SN65HVD75DR
NT1: NetTie_2; NetTie-2_SMD_Pad0.5mm
R301, R305: 10k; R_0603_1608Metric_Pad0.98x0.95mm_HandSolder; MPN 0603WAF1002T5E; LCSC C25804
R302, R304: 10R; R_0603_1608Metric_Pad0.98x0.95mm_HandSolder; MPN CRCW060310R0FKTA; LCSC C2091419
R303: 120R; R_0603_1608Metric_Pad0.98x0.95mm_HandSolder; MPN 0603WAF1200T5E; LCSC C22787
TP301, TP302, TP303: TestPoint_Small; TestPoint_Pad_D1.5mm

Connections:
/DSP_RS485_A/Y: D301.2 (A2), R303.2, R304.1; also elsewhere on the board
/DSP_RS485_B/Z: D301.1 (A1), R302.2, R303.1; also elsewhere on the board
/MCU/IO18: IC301.4 (D), TP301.1; also elsewhere on the board
/MCU/IO19: IC301.3 (DE), R305.1, TP302.1; also elsewhere on the board
/MCU/IO27: IC301.1 (R), R301.2, TP303.1; also elsewhere on the board
/RS485/RS485_A: IC301.6 (A), R304.2
/RS485/RS485_B: IC301.7 (B), R302.1
/RS485/~RE: IC301.2 (~RE), NT1.2
GND: C301.2, D301.3 (common), IC301.5 (GND), NT1.1, R305.2; also elsewhere on the board
VCC: C301.1, IC301.8 (VCC), R301.1; also elsewhere on the board

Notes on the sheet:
KEEP CLOSE TO CONNECTOR
TVS PROT AS PER DATASHEET FIG. 31 PG 25 AND BOM TABLE. 4 PG 22
PULSE PROOF THICK FILM

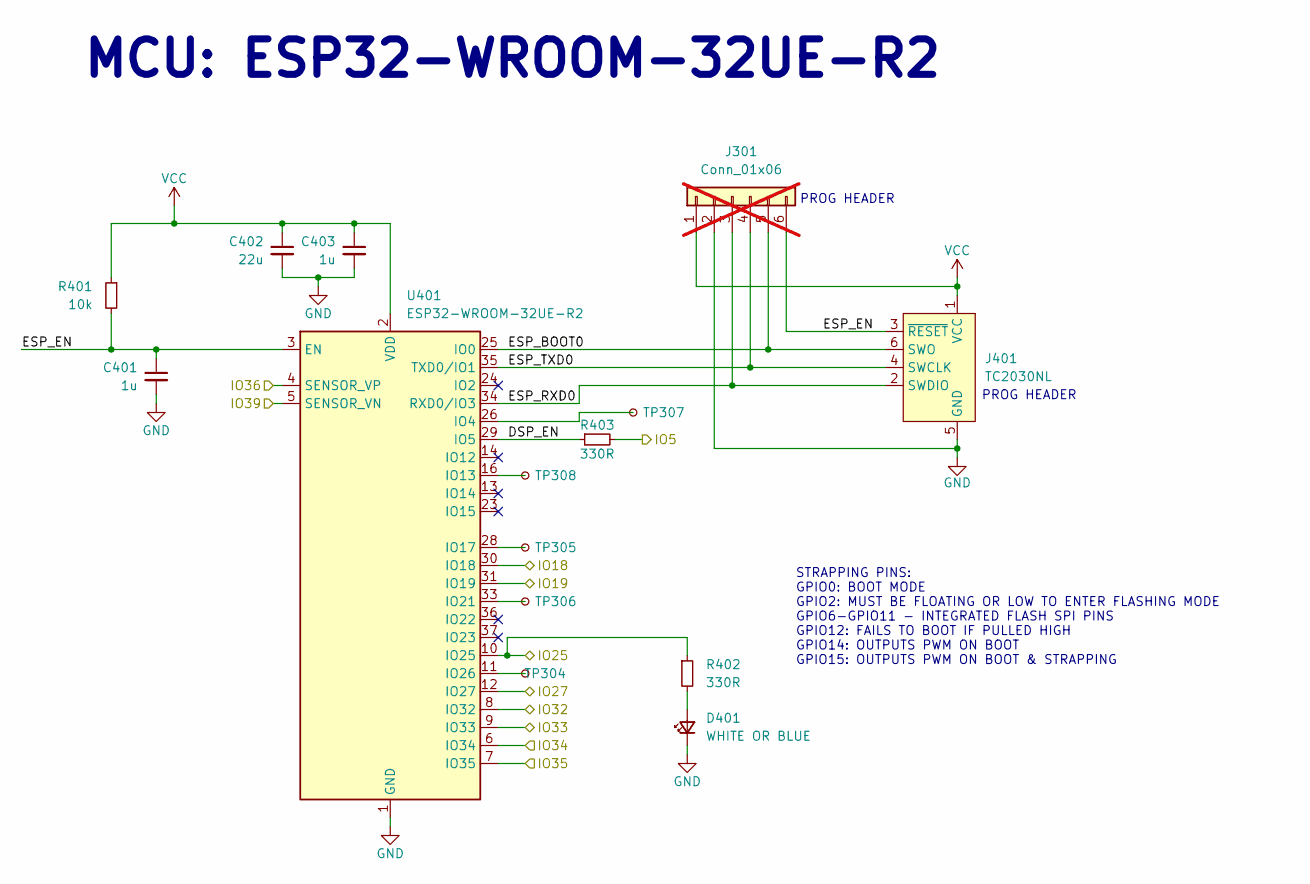
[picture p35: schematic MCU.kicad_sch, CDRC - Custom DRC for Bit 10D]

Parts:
C401, C403: 1u; C_0603_1608Metric_Pad1.08x0.95mm_HandSolder; MPN CL10A105KB8NNNC; LCSC C15849
C402: 22u; C_0805_2012Metric_Pad1.18x1.45mm_HandSolder; MPN CL21A226MAQNNNE; LCSC C45783
D401: WHITE OR BLUE; LED_0603_1608Metric_Pad1.05x0.95mm_HandSolder; MPN KT-0603W; LCSC C2290
J301: Conn_01x06; PinSocket_1x06_P2.54mm_Vertical; not fitted
J401: TC2030NL; Tag-Connect_TC2030-IDC-FP_2x03_P1.27mm_Vertical
R401: 10k; R_0603_1608Metric_Pad0.98x0.95mm_HandSolder; MPN 0603WAF1002T5E; LCSC C25804
R402, R403: 330R; R_0603_1608Metric_Pad0.98x0.95mm_HandSolder; MPN 0603WAF3300T5E; LCSC C23138
TP304, TP305, TP306, TP307, TP308: TestPoint_Small; TestPoint_Pad_D1.5mm
U401: ESP32-WROOM-32UE-R2; ESP32-WROOM-32UE; MPN ESP32-WROOM-32UE-N16; LCSC C701346

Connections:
/DSP_POWER_EN: R403.2; also elsewhere on the board
/MCU/DSP_EN: R403.1, U401.29 (IO5)
/MCU/ESP_BOOT0: J301.5, J401.6 (SWO), U401.25 (IO0)
/MCU/ESP_EN: C401.1, J301.6, J401.3 (~RESET), R401.2, U401.3 (EN)
/MCU/ESP_RXD0: J301.3, J401.2 (SWDIO), U401.34 (RXD0/IO3)
/MCU/ESP_TXD0: J301.4, J401.4 (SWCLK), U401.35 (TXD0/IO1)
/MCU/IO18: U401.30 (IO18); also elsewhere on the board
/MCU/IO19: U401.31 (IO19); also elsewhere on the board
/MCU/IO25: R402.1, U401.10 (IO25); also elsewhere on the board
/MCU/IO27: U401.12 (IO27); also elsewhere on the board
/MCU/IO32: U401.8 (IO32); also elsewhere on the board
/MCU/IO33: U401.9 (IO33); also elsewhere on the board
/MCU/IO34: U401.6 (IO34); also elsewhere on the board
/MCU/IO35: U401.7 (IO35); also elsewhere on the board
/MCU/IO36: U401.4 (SENSOR_VP); also elsewhere on the board
/MCU/IO39: U401.5 (SENSOR_VN); also elsewhere on the board
GND: C401.2, C402.2, C403.2, D401.1 (K), J301.2, J401.5 (GND), U401.1 (GND), U401.15 (GND), U401.38 (GND), U401.39 (GND); also elsewhere on the board
unnamed: D401.2 (A), R402.2
unnamed: TP307.1, U401.26 (IO4)
unnamed: TP308.1, U401.16 (IO13)
unnamed: TP305.1, U401.28 (IO17)
unnamed: TP306.1, U401.33 (IO21)
unnamed: TP304.1, U401.11 (IO26)
VCC: C402.1, C403.1, J301.1, J401.1 (VCC), R401.1, U401.2 (VDD); also elsewhere on the board

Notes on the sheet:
PROG HEADER
MCU: ESP32-WROOM-32UE-R2
STRAPPING PINS: GPIO0: BOOT MODE GPIO2: MUST BE FLOATING OR LOW TO ENTER FLASHING MODE GPIO6-GPIO11 - INTEGRATED FLASH SPI PINS GPIO12: FAILS TO BOOT IF PULLED HIGH GPIO14: OUTPUTS PWM ON BOOT GPIO15: OUTPUTS PWM ON BOOT & STRAPPING

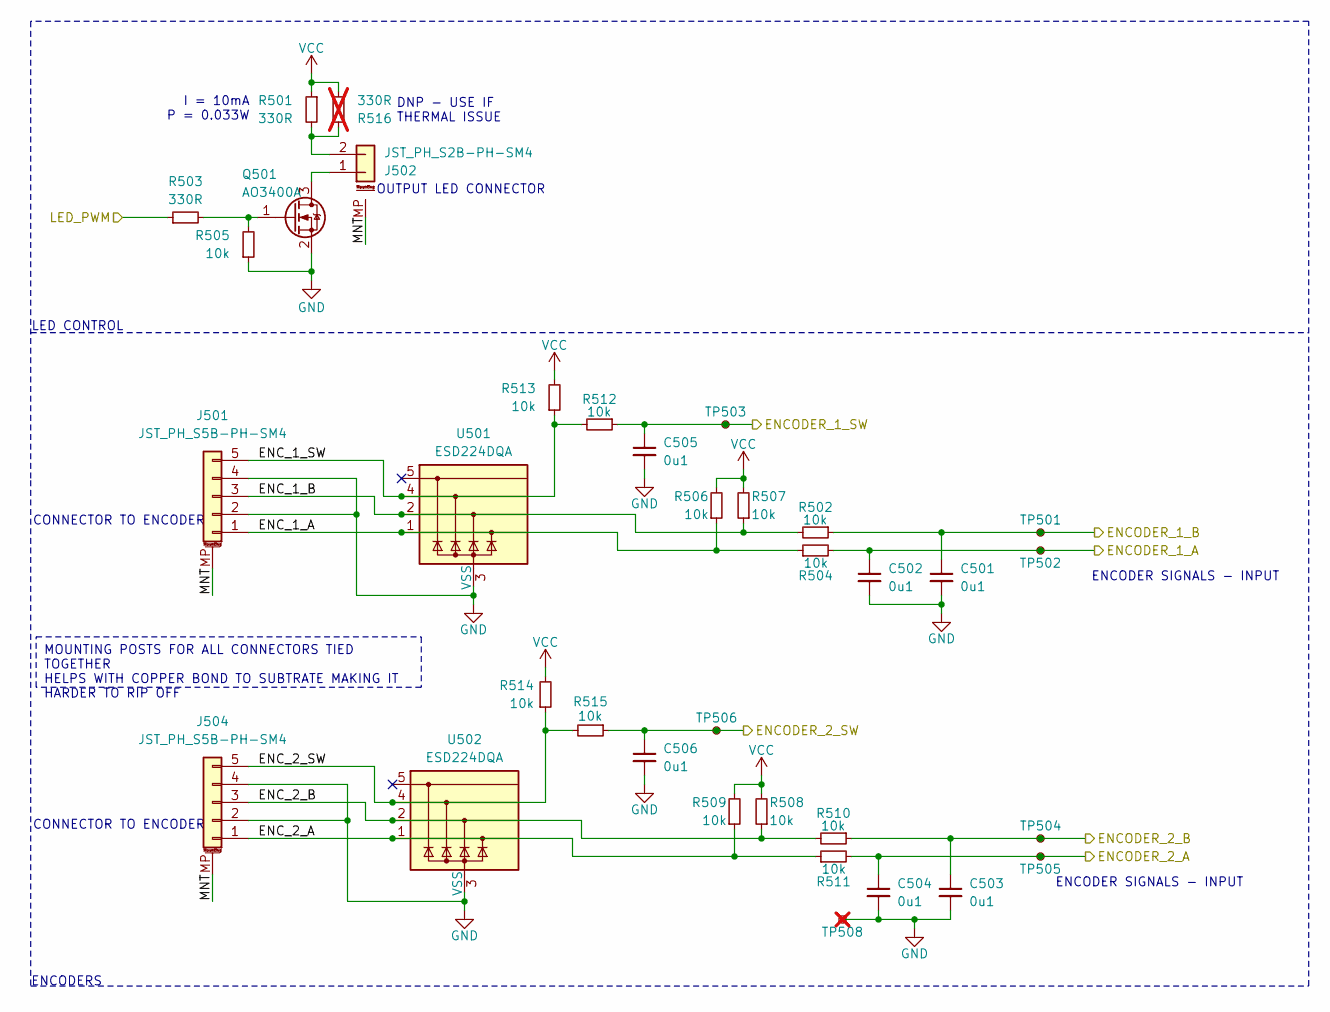
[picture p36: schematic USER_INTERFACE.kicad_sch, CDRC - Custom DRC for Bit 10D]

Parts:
C501, C502, C503, C504, C505, C506: 0u1; C_0603_1608Metric_Pad1.08x0.95mm_HandSolder; MPN CC0603KRX7R9BB104; LCSC C14663
J501, J504: JST_PH_S5B-PH-SM4; JST_PH_S5B-PH-SM4-TB_1x05-1MP_P2.00mm_Horizontal; MPN S5B-PH-SM4-TB(LF)(SN); LCSC C265104
J502: JST_PH_S2B-PH-SM4; JST_PH_S2B-PH-SM4-TB_1x02-1MP_P2.00mm_Horizontal; MPN S2B-PH-SM4-TB(LF)(SN); LCSC C295747
Q501: AO3400A; SOT-23; MPN AO3400A; LCSC C20917
R501, R503: 330R; R_0603_1608Metric_Pad0.98x0.95mm_HandSolder; MPN 0603WAF3300T5E; LCSC C23138
R502, R504, R505, R506, R507, R508, R509, R510, R511, R512, R513, R514, R515: 10k; R_0603_1608Metric_Pad0.98x0.95mm_HandSolder; MPN 0603WAF1002T5E; LCSC C25804
R516: 330R; R_1206_3216Metric_Pad1.30x1.75mm_HandSolder; MPN 1206W4J0331T5E; LCSC C25374; not fitted
TP501, TP502, TP503, TP504, TP505, TP506: TestPoint_Small; TestPoint_Pad_D1.5mm
TP508: TestPoint_Small; TestPoint_Keystone_5000-5004_Miniature; MPN RH-5001; LCSC C5199801; not fitted
U501, U502: ESD224DQA; Diodes_UDFN-10_1.0x2.5mm_P0.5mm; MPN RClAMP3324P-ES; LCSC C5199157

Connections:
/MCU/IO25: R503.1; also elsewhere on the board
/MCU/IO32: C501.1, R502.1, TP501.1; also elsewhere on the board
/MCU/IO33: C505.1, R512.1, TP503.1; also elsewhere on the board
/MCU/IO34: C506.1, R515.1, TP506.1; also elsewhere on the board
/MCU/IO35: C502.1, R504.2, TP502.1; also elsewhere on the board
/MCU/IO36: C504.1, R511.2, TP505.1; also elsewhere on the board
/MCU/IO39: C503.1, R510.1, TP504.1; also elsewhere on the board
/USER_INTERFACE/ENC_1_A: J501.1, R504.1, R506.1, U501.1, U501.10
/USER_INTERFACE/ENC_1_B: J501.3, R502.2, R507.1, U501.2, U501.9
/USER_INTERFACE/ENC_1_SW: J501.5, R512.2, R513.1, U501.4, U501.7
/USER_INTERFACE/ENC_2_A: J504.1, R509.1, R511.1, U502.1, U502.10
/USER_INTERFACE/ENC_2_B: J504.3, R508.1, R510.2, U502.2, U502.9
/USER_INTERFACE/ENC_2_SW: J504.5, R514.1, R515.2, U502.4, U502.7
/USER_INTERFACE/MNT: J501.MP (MountPin), J502.MP (MountPin), J504.MP (MountPin)
GND: C501.2, C502.2, C503.2, C504.2, C505.2, C506.2, J501.2, J501.4, J504.2, J504.4, Q501.2 (S), R505.1, TP508.1, U501.3 (VSS), U501.8 (VSS), U502.3 (VSS), U502.8 (VSS); also elsewhere on the board
unnamed: J502.1, Q501.3 (D)
unnamed: J502.2, R501.2, R516.1
unnamed: Q501.1 (G), R503.2, R505.2
VCC: R501.1, R506.2, R507.2, R508.2, R509.2, R513.2, R514.2, R516.2; also elsewhere on the board

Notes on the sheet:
MOUNTING POSTS FOR ALL CONNECTORS TIED TOGETHER HELPS WITH COPPER BOND TO SUBTRATE MAKING IT HARDER TO RIP OFF
ENCODER SIGNALS - INPUT
OUTPUT LED CONNECTOR
CONNECTOR TO ENCODER
LED CONTROL
I = 10mA P = 0.033W
ENCODERS
DNP - USE IF THERMAL ISSUE

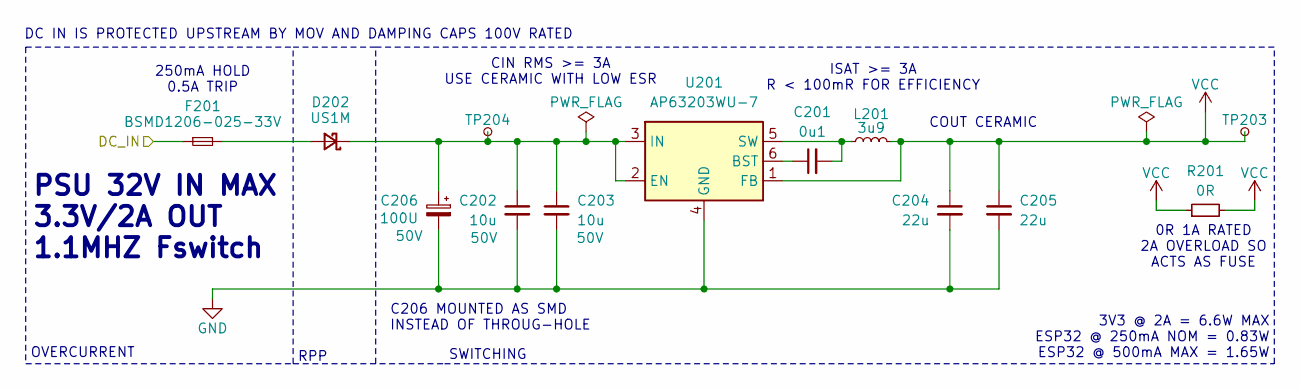
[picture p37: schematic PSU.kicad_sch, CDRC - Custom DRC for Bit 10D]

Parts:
C201: 0u1; C_0603_1608Metric_Pad1.08x0.95mm_HandSolder; MPN CC0603KRX7R9BB104; LCSC C14663
C202, C203: 10u; C_1206_3216Metric_Pad1.33x1.80mm_HandSolder; Voltage Rating 50V; MPN CL31B106KBHNNNE; LCSC C89632
C204, C205: 22u; C_0805_2012Metric_Pad1.18x1.45mm_HandSolder; MPN CL21A226MAQNNNE; LCSC C45783
C206: 100U; Capacitor_D6.3xL12mm_SMD; Voltage Rating 50V; MPN ERZ1HM101E12OT; LCSC C160200
D202: US1M; D_SMA_Handsoldering; MPN US1M; LCSC C412437
F201: BSMD1206-025-33V; Fuse_1206_3216Metric_Pad1.42x1.75mm_HandSolder; MPN BSMD1206-025-33V; LCSC C2977524
L201: 3u9; L_Cenker_CKCS4030; MPN SWPA4030S3R9MT; LCSC C96899
R201: 0R; R_0603_1608Metric_Pad0.98x0.95mm_HandSolder; MPN 0603WAF0000T5E; LCSC C21189
TP203, TP204: TestPoint_Small; TestPoint_Pad_D1.5mm
U201: AP63203WU-7; TSOT-23-6; MPN AP63203WU-7; LCSC C780769

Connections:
/DSP_CONST_12V: F201.1; also elsewhere on the board
GND: C202.2, C203.2, C204.2, C205.2, C206.2, U201.4 (GND); also elsewhere on the board
unnamed: D202.2 (A), F201.2
unnamed: C202.1, C203.1, C206.1, D202.1 (K), TP204.1, U201.2 (EN), U201.3 (IN)
unnamed: C201.1, U201.6 (BST)
unnamed: C201.2, L201.1, U201.5 (SW)
VCC: C204.1, C205.1, L201.2, R201.1, R201.2, TP203.1, U201.1 (FB); also elsewhere on the board

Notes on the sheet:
COUT CERAMIC
3V3 @ 2A = 6.6W MAX ESP32 @ 250mA NOM = 0.83W ESP32 @ 500mA MAX = 1.65W
OVERCURRENT
ISAT >= 3A R < 100mR FOR EFFICIENCY
C206 MOUNTED AS SMD INSTEAD OF THROUG-HOLE
DC IN IS PROTECTED UPSTREAM BY MOV AND DAMPING CAPS 100V RATED
RPP
0R 1A RATED 2A OVERLOAD SO ACTS AS FUSE
CIN RMS >= 3A USE CERAMIC WITH LOW ESR
PSU 32V IN MAX 3.3V/2A OUT 1.1MHZ Fswitch
250mA HOLD 0.5A TRIP
SWITCHING

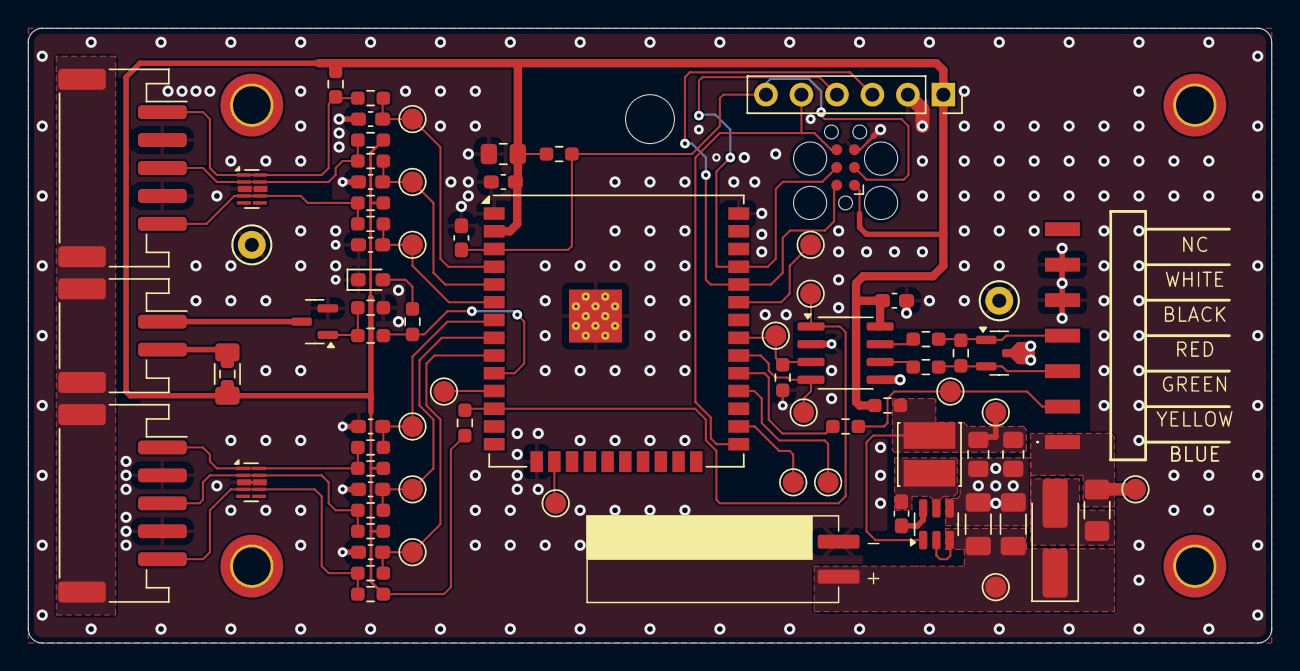
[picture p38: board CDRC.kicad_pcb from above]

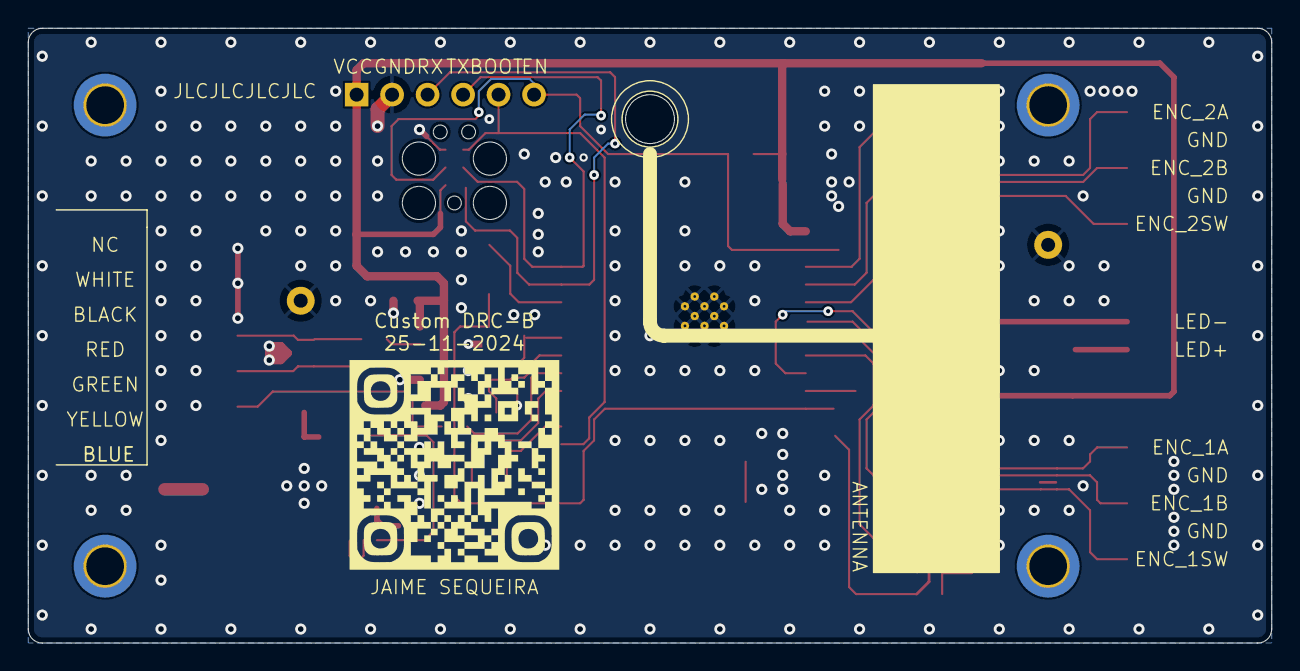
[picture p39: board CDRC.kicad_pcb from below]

Board: 2 copper layers, 89.0 x 44.0 mm, 83 parts (4 on the bottom side), 44 nets.

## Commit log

2025-06-17 A fresh start for branch
    [AudisonDRCReverseEngineered.kicad_pcb, AudisonDRCReverseEngineered.kicad_sch, BOM-CDRC.csv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]
2025-12-12 Repo restructure - this repo is now only for HW
    [CDRC-CaseBase.stl, CDRC-CaseLid.stl, CustomDRC_Cover.step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]
